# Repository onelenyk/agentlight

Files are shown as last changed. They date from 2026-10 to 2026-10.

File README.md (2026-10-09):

# AgentLight

Маленька лампа на ESP32-C3 Super Mini, яка кольором показує, що зараз робить AI-агент. Стоїть на столі, живиться від USB-C, стани отримує по WiFi від хуків агента — Claude Code, OpenCode, Antigravity, Codex та інших — або як MCP-сервер.

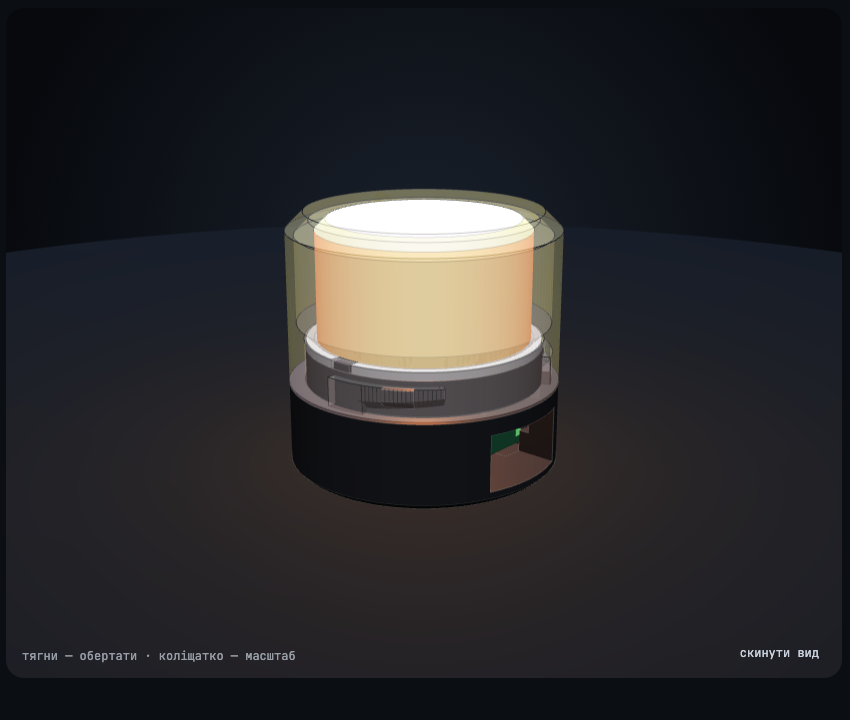
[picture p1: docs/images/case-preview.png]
Корпус у зборі


| Світло | Що означає |
|---|---|
| оранжевий, «дихає» | агент працює |
| червоний, блимає | агент чекає на тебе: дозвіл або питання |
| червоний, рівний | помилка |
| зелений | готово |
| синій, «дихає» | лампа чекає налаштування WiFi |
| фіолетовий, «дихає» | немає WiFi |

Якщо агентів кілька, лампа показує найважливіший стан: помилка > чекає > працює > готово.

## Що вона вміє

- **Показувати стан агентів** — працює, чекає на тебе, готово, помилка; на сторінці лампи видно кожну сесію: проєкт, запит, поточну дію.
- **Підключатись до агента однією командою** — хуки й встановлювач лежать у самій лампі.
- **П'ять режимів:** стан агентів, просто лампа з кольором та анімацією, таймер фокусу, шість ігор, Bluetooth-пульт для музики.
- **Сенсор:** дотик, подвійний дотик і утримання виконують дії, свої в кожному режимі; довге утримання перемикає режим.
- **Пульт:** лампа — ще й Bluetooth-клавіатура: керує музикою на комп'ютері чи планшеті й шле клавіші F13–F16, на які можна повісити свої команди.
- **Налаштовуватись без кабелю** — через власну точку доступу або по Bluetooth; пам'ятає до п'яти мереж WiFi.
- **Оновлюватись однією кнопкою** — прошивку збирає й підписує GitHub Actions, лампа приймає лише підписану.
- **Дозволяти агентові дію дотиком** — експериментально, для Claude Code й OpenCode.

## Що в репозиторії

| Тека | Що там | Документ |
|---|---|---|
| [`firmware/`](firmware/) | прошивка (PlatformIO, Arduino) і тестова прошивка для перевірки пайки | [docs/firmware.md](docs/firmware.md) |
| [`case/`](case/) | параметрична модель корпусу, перевірка, файли до друку, 3D-превью | [docs/case.md](docs/case.md) |
| [`hooks/`](hooks/) | хуки для Claude Code, OpenCode, Codex та інших агентів і встановлювач; лампа роздає їх сама | [docs/hooks.md](docs/hooks.md) |
| [`web/`](web/) | сайт: налаштування WiFi по Bluetooth і вхід до 3D-превью; локальний сервер | [docs/site.md](docs/site.md) |
| [`docs/`](docs/) | компоненти, схема підключення, складання | [docs/bom.md](docs/bom.md), [docs/wiring.md](docs/wiring.md) |

Стани лампи й те, які агенти крім Claude Code можна підключити: [docs/agents.md](docs/agents.md).

Звіт останньої наскрізної перевірки на справжній лампі: [docs/e2e-report.md](docs/e2e-report.md). Автоматичні тести й те, що вони ловлять: [docs/testing.md](docs/testing.md). Що заплановано далі: [docs/roadmap.md](docs/roadmap.md).

## Зібрати свою

1. **Купити деталі** — [список компонентів](docs/bom.md): плата, три діоди на круглих платках, сенсорна кнопка, резистор, дріт.
2. **Надрукувати корпус** — п'ять деталей у трьох кольорах, без підтримок: [файли й налаштування](docs/case.md).
3. **Спаяти** — [схема й порядок пайки](docs/wiring.md).
4. **Прошити** — `cd firmware && pio run -t upload`: [прошивка](docs/firmware.md).
5. **Підключити до WiFi** — по Bluetooth зі сторінки `web/setup.html` або через точку доступу лампи: [сайт](docs/site.md).
6. **Під'єднати агента** — одна команда зі сторінки лампи: [підключення агентів](docs/hooks.md).

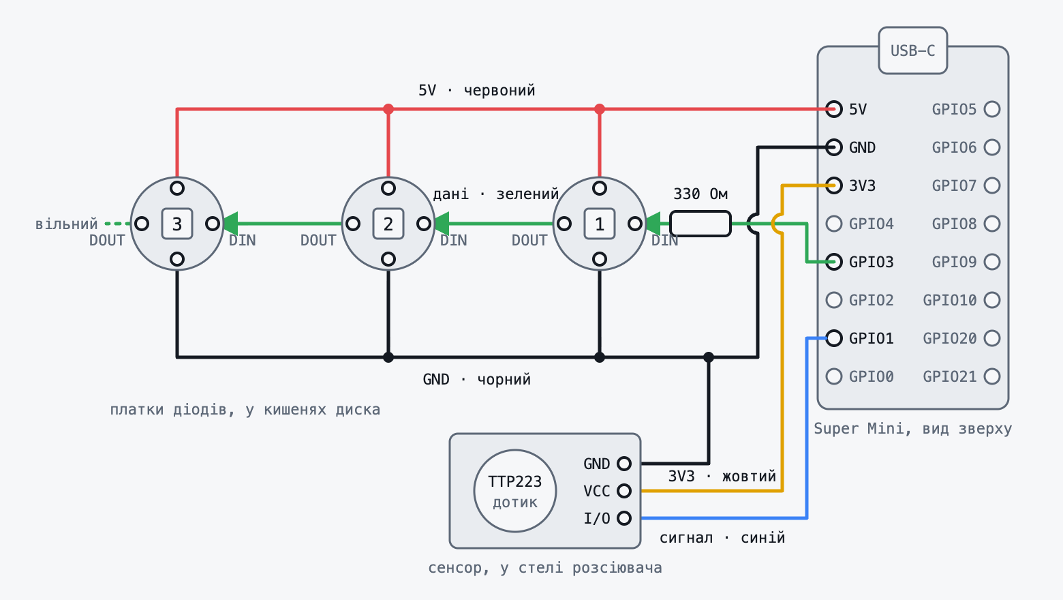
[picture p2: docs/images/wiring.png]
Схема підключення


## Швидкий старт на новій машині

```sh
git clone https://github.com/onelenyk/agentlight.git && cd agentlight

python3 web/serve.py                       # сайт: http://localhost:8791/web/

cd firmware && pio run -t upload           # прошивка (потрібен PlatformIO)

python3 -m venv .venv && .venv/bin/pip install -r case/requirements.txt
.venv/bin/python case/build.py             # перебудувати корпус
.venv/bin/python case/verify.py            # перевірити його
```

## Стан проєкту

Усе, що можна перевірити без пальця на сенсорі й без очей, проходить наскрізну перевірку на справжній лампі — результати й спосіб у [docs/e2e-report.md](docs/e2e-report.md). Автотести без лампи йдуть на кожен коміт, перевірка на свіжих версіях програм агентів — щотижня: [docs/testing.md](docs/testing.md).

Агенти:

| Агент | Перевірено на справжній програмі | Не перевірено |
|---|---|---|
| Claude Code | усі п'ять станів; «Дозволити» | чи видно питання у вікні, поки лампа чекає дотику |
| OpenCode | «працює» з назвою інструмента, «готово» | запит дозволу, помилка, відповідь лампи на запит дозволу |
| Antigravity IDE | «працює», «готово» (вручну) | помилка; стану «чекає» немає взагалі |
| Codex CLI | «працює», закриття сесії (без входу в акаунт) | «готово», «чекає» |
| Qwen Code | «працює» (без входу в акаунт) | решта станів |
| Copilot CLI, Cursor, Gemini CLI | — | усе: не запускаються без акаунта або не встановлені |

Перевірено руками власника: корпус надрукований і зібраний, деталі сидять добре; налаштування WiFi через точку доступу й по Bluetooth зі сторінки в Chrome; пульт працює з Mac та iPad.

Лишається перевіряти лише руками: жести на живому сенсорі, вигляд анімацій, ігри пальцем, «Дозволити» з живим дотиком.

Обмеження, про які варто знати:

- **Захист мінімальний.** Будь-хто у твоїй мережі WiFi може міняти стан і налаштування лампи; будь-хто поруч із Bluetooth — додати чи забути мережу. Захищені лише оновлення прошивки (підпис або пароль) і «Дозволити» (спарювання дотиком і підпис відповіді).
- **Автоматичного відкату прошивки немає:** якщо оновлення не вийде в WiFi, рятує кабель.
- **Хуки шукають лампу за іменем `agentlight.local`.** На Mac це працює; на частині Linux-систем треба вписати IP. Windows без WSL не підтримується.
- **Сторінка лампи лише українською.**

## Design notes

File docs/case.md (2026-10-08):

# Корпус

Ø38 × 36,1 мм, п'ять деталей, друк без підтримок і без AMS. Модель параметрична, на Python (manifold3d + trimesh): усі розміри й зазори — у `case/build.py`.

| У зборі | Розріз |
|---|---|
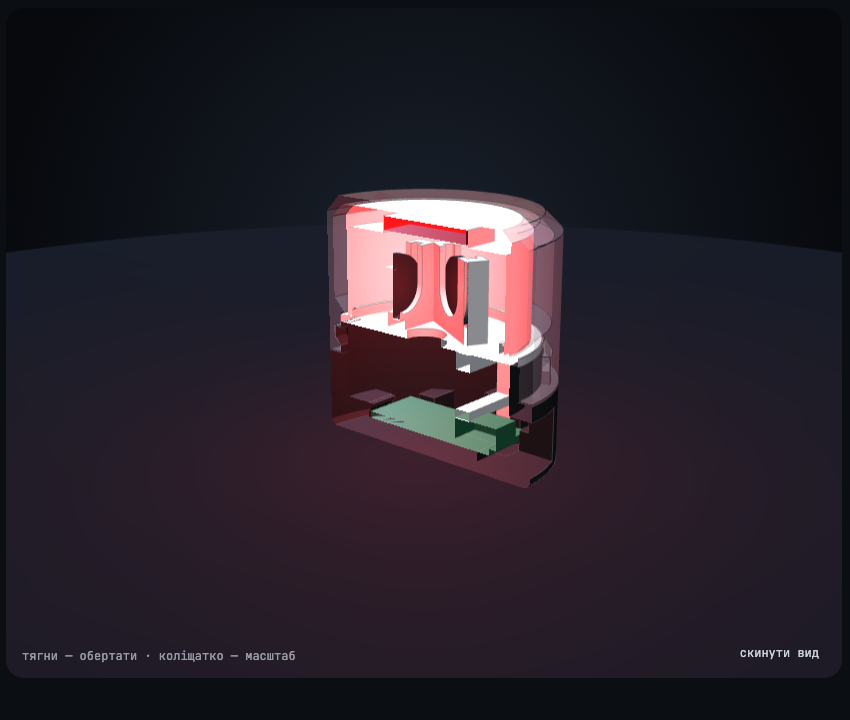
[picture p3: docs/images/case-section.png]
Розріз
| У зборі |  |

Покрутити, розібрати і приміряти кольори: `case/preview/index.html` (або `python3 web/serve.py` і «Корпус у 3D»).

## Деталі

| Деталь | Файл | Філамент | На столі, мм | Як лежить | Навіщо |
|---|---|---|---|---|---|
| основа | `base.stl` | чорний | 38 × 38 × 18 | дном донизу | тримає плату, тунель під USB-C, шийка з байонетом |
| рамка | `clamp.stl` | білий | 15,3 × 23,4 × 2,5 | плазом | притискає плату за корпус USB-роз'єму |
| диск із кишенями | `carrier.stl` | білий | 33 × 32,8 × 12,9 | диском донизу | три кишені під платки діодів, колодязь для дротів |
| розсіювач | `diffuser.stl` | білий | 30 × 30 × 16,8 | догори дном | розмиває світло і ховає нутрощі; у стелі гніздо під сенсор |
| ковпак | `dome.stl` | прозорий | 38 × 38 × 23,8 | догори дном | зовнішня оболонка, замикається поворотом |

## Файли до друку

Усе лежить у `case/stl/`, деталі вже в положенні для друку.

| Плита | Що в ній | Філамент |
|---|---|---|
| `plate_black.3mf` | основа | чорний |
| `plate_white.3mf` | диск із кишенями, розсіювач, рамка | білий |
| `plate_clear.3mf` | ковпак | прозорий |

Поруч ті самі деталі окремими STL — для іншого розкладу кольорів. Деталі у 3MF лежать від кута координат; якщо слайсер не відцентрує їх сам, натисни «Arrange».

## Налаштування слайсера

- Шар 0,2 мм, сопло 0,4 мм.
- Без підтримок. Єдине нависання — стеля тунелю USB, це міст 14 мм між двома стінками.
- Компенсацію «слонячої ноги» лиши ввімкненою: на неї розраховані посадки рамки й диска.
- Для ковпака й розсіювача шов постав «ззаду» або «вирівняний».
- Крізь прозорий низ ковпака видно шийку основи із зубами. Щоб сховати — заміна філаменту на висоті 15,5 мм дасть непрозорий поясок.

## Як воно тримається

- **Ковпак** надягається на шийку основи: три зуби заходять у вертикальні пази, далі поворот за годинниковою. Полиця паза плавно піднімається і затягує ковпак донизу приблизно на 25° з 35° ходу.
- **Розсіювач** на 0,1 мм вищий за місце під ковпаком, тож закручений ковпак притискає його до диска — він не бовтається.
- **Плата** лежить на ребрі, заднім краєм під гачком; спереду її тримає рамка, якій диск не дає піднятись.
- **Сенсор** сидить у гнізді товстої (3,2 мм) стелі розсіювача. Крізь неї модуль не видно, а до пальця лишається 2,0 мм пластику: 0,8 білого і 1,2 прозорого.

## Зазори

| Де | Зазор, мм |
|---|---|
| шийка основи в спідниці ковпака | 0,20 на радіус |
| зуб у пазу ковпака | 0,30 |
| диск у ковпаку | 0,30 на радіус |
| плата в гнізді | 0,20 з боків, 0,30 по довжині |
| платка діода в кишені | 0,20 на радіус, паз 1,5 мм |
| ніжка рамки в пазу | 0,20 з боку |
| рамка до диска | 0,15 |
| сенсор у гнізді (15,5 × 11,5 × 2,4 мм) | 0,25 з боку |
| розсіювач на бортику диска | 0,10 на радіус |
| розсіювач під ковпаком | −0,10 (натяг) |
| рамка на роз'ємі USB | −0,15 (натяг) |

Найтонші елементи: стінка розсіювача й шар над сенсором 0,8 мм, губи кишень 0,9 мм, стінка ковпака в пазах 1,0 мм.

## Перебудувати і перевірити

```sh
python3 -m venv .venv && .venv/bin/pip install -r case/requirements.txt
.venv/bin/python case/build.py            # STL і 3MF у case/stl/
.venv/bin/python case/verify.py           # перевірка, код виходу 1 при проблемах
.venv/bin/python case/export_preview.py   # оновити моделі на сторінці превью
```

`verify.py` перевіряє: сітки замкнені й кожна деталь — одне тіло; деталі стоять на столі й не мають нависань понад 45° (крім моста над тунелем); у складеному стані нічого не перетинається, крім двох задуманих натягів; кожна деталь доходить до місця без зачіпань; ковпак після повороту не знімається і затягує навіть при відхиленні висоти на ±0,2 мм.

Корпус надрукований на Bambu A1 mini і зібраний: деталі сидять добре, розсіювач під ковпаком не бовтається.

Чого перевірка не бачить: реальну точність принтера і розміри твоїх деталей. Перед друком звір штангенциркулем три розміри, взяті як типові:

| Параметр у `build.py` | Значення | Що це |
|---|---|---|
| `PCB_T` | 1,0 мм | товщина плати ESP |
| `LED_PCB_T` | 1,2 мм | товщина платки діода без самого діода |
| `TOUCH_L`, `TOUCH_W`, `TOUCH_T` | 15 × 11 × 2 мм | модуль TTP223 з деталями |

Якщо замок ковпака вийде тугим або вільним — це `FIT`; якщо розсіювач бовтається або не дає докрутити ковпак — `DIFF_PRELOAD`.

Тексти й таблиці на сторінці превью після зміни моделі треба оновити вручну: `export_preview.py` міняє лише 3D-моделі.

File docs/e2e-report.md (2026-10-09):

# Звіт наскрізної перевірки

Дата: 9 жовтня 2026. Прошивка: 0.12.0. Лампа: `AgentLight-4750` (ESP32-C3 Super Mini, три діоди, сенсор TTP223), у домашній мережі WiFi.

## Підсумок

**67 перевірок із 68 пройшли, одна пропущена, жодна не впала.** Перевірено все, що можна перевірити без пальця на сенсорі й без очей: лампа через мережу, справжні програми агентів, оновлення прошивки, Bluetooth, сайт.

Пропущена перевірка — «клавіша гучності з лампи міняє гучність цього Mac»: під час прогону активним пристроєм пульта був iPad. Те, що клавіші отримує лише вибраний пристрій, підтвердила сусідня перевірка.

Це другий повний прогін. Перший, на версії 0.11.0, знайшов три справжні вади; вони виправлені в 0.11.1. Нинішній нових вад лампи не знайшов, але показав дві слабкості самої перевірки — про них нижче.

Чого ця перевірка не охоплює — у розділі «Що лишилось перевірити руками»: насамперед жести на живому сенсорі та вигляд світла.

## Як перевіряли

Усі перевірки зібрані в `tests/e2e_lamp.py` і запускаються однією командою проти живої лампи:

```sh
python3 tests/e2e_lamp.py --lamp 192.168.110.67
```

Що в ній справжнє, а що ні:

| Що | Справжнє | Замінено |
|---|---|---|
| Лампа | так: справжня плата в мережі, справжня прошивка | — |
| Claude Code 2.1.295, Codex CLI 0.162.0, Qwen Code 0.25.0, OpenCode 1.18.35 | так: свіжі версії справжніх програм, хуки поставлені встановлювачем із лампи | модель: замість API стоїть імітація на тому ж комп'ютері, тож акаунт і гроші не потрібні. Codex і Qwen запускались без входу в акаунт і до відповіді моделі не доходять |
| Оновлення прошивки | так: лампа справді перепрошивалась понад десять разів, і щоразу звірявся час збірки | — |
| Bluetooth | так: пошук, читання й запис із цього Mac; два спаровані пристрої (Mac та iPad), і клавіша гучності з лампи міняє гучність Mac лише тоді, коли активний він | — |
| Дотик до сенсора | **ні** | у розділі «Дозволити» дотик імітувала окрема збірка прошивки з прапорцем `ALLOW_TEST_TOUCH`. У випущених збірках такого шляху немає, і це теж перевірено |
| Очі | **ні** | колір і анімацію діодів перевірка не бачить — лише те, що лампа каже про свій стан |

Додатково сторінку лампи пройдено у справжньому Chrome: перемикання всіх п'яти режимів, запуск і скидання таймера, вибір гри й дотик зі сторінки, зміна кольору лампи, стан пульта, перевірка оновлень, розділ «Дозволити». Помилок на сторінці не було.

Окремо від цього на кожен коміт у GitHub Actions ідуть 40 автотестів без лампи (`tests/test_agentlight.py`) і раз на тиждень — перевірка на свіжих версіях програм агентів (`tests/canary.py`). Обидва зелені.

## Що знайшла перевірка

### Цей прогін, 0.12.0

Вад лампи не знайдено. Дві слабкості самої перевірки, обидві виправлені:

- **Оновлення через PlatformIO один раз не пройшло.** Вручну пройшло одразу, за 39 секунд, і в наступних трьох прогонах теж. Схоже, одразу після навмисно відхиленої спроби з невірним паролем лампа ще не готова прийняти наступну; справжня причина не встановлена. Перевірка тепер робить одну повторну спробу й пише, якщо вона знадобилась.
- **Після тієї невдачі на лампі лишився тестовий пароль оновлення**, якого вже ніхто не знав: перевірка не дійшла до свого прибирання. Оновлення однією кнопкою це не зачіпало, але свій файл залити стало б неможливо. Пароль знято службовою підписаною збіркою, яка стирає його при запуску. Перевірка тепер має сталий пароль і знімає його окремим кроком за будь-якого результату.

Побічний результат: у прошивці з'явився спосіб зняти забутий пароль оновлення без стирання всієї лампи — підписаною збіркою з прапорцем `OTA_FORGET_PASSWORD`. Зібрати й підписати таку може лише власник ключа підпису.

### Перший прогін, 0.11.0

Справжні вади, виправлені в 0.11.1:

| Вада | Наслідок для власника | Виправлення |
|---|---|---|
| Плагін OpenCode не діставав до лампи за іменем `agentlight.local` | з коробки OpenCode на Mac лампу не засвічував узагалі: пошук імені тривав 5 секунд, а плагін чекав 2 | плагін сам шукає лампу лише в IPv4 (9 мс) і шле стани по одному, в порядку появи |
| Лампу не було видно по Bluetooth, поки до неї підключений спарований комп'ютер | після спарювання пульта ніхто інший не міг знайти лампу, щоб налаштувати WiFi | лампа сама відновлює оголошення, поки є вільне з'єднання |
| «Спокій» від Claude Code при виході надсилав фоновий процес, який вихід міг обірвати | закрита сесія могла висіти на лампі до кінця свого часу | хук кінця сесії тепер сам чекає на запит, до секунди |

Про третю чесно: чи губився «спокій» насправді, я не встановив — у перших прогонах його відсутність пояснювалась помилкою самої перевірки. Виправлення зроблене за документацією Claude Code, яка каже, що фонові хуки при виході обриваються.

Помилки самої перевірки (лампа поводилась правильно):

- перевірка плутала тестову сесію Claude Code зі справжньою, яка в цей час теж була на лампі;
- відповідь «202» від лампи вона приймала за «200»;
- сайт за Cloudflare відхиляв її запит через спосіб звернення.

Ще одне спостереження з роботи, не вада: macOS, уперше побачивши лампу як клавіатуру, просить натиснути клавіші біля Shift. У 0.11.1 на сторінці лампи з'явились дві кнопки, що їх натискають.

## Результати

### Основа

| Перевірка | Пройшла | Подробиці |
|---|---|---|
| лампа відповідає й каже, хто вона | так | версія 0.12.0, зібрана Oct  9 2026 07:31:43, вільно 122 КБ |
| ім'я agentlight.local веде на цю лампу | так |  |
| сторінка віддається стиснутою й містить усі режими | так | 14.0 КБ у мережі, 36 КБ розгорнута |
| невідома адреса дає 404 | так |  |

### Агенти

| Перевірка | Пройшла | Подробиці |
|---|---|---|
| стан приймається тілом JSON і параметрами запиту | так |  |
| назва й завдання зберігаються, повідомлення — ні | так |  |
| лампа показує найважливіший стан | так | готово < працює < чекає < помилка |
| idle прибирає агента; невідомий стан відхиляється | так |  |
| більше восьми агентів: найстаріший витісняється | так |  |
| довгий текст обрізається без поламаних літер | так |  |
| «прибрати всіх» очищає список | так |  |

### Хуки агентів

| Перевірка | Пройшла | Подробиці |
|---|---|---|
| усі зразки подій лампа розбирає так само, як тести | так | 30 зразків від семи агентів |
| лампа роздає ті самі файли хуків, що в репозиторії | так | 10 файлів і встановлювач |
| встановлювач із лампи ставить хуки всім восьми агентам | так | claude, codex, gemini, qwen, cursor, antigravity, copilot, opencode |
| встановлений хук Claude Code доходить до лампи за її іменем | так |  |

### Справжні програми агентів

| Перевірка | Пройшла | Подробиці |
|---|---|---|
| Claude Code: відповідь — працює, готово, спокій | так | 2.1.295 (Claude Code) |
| Claude Code: виклик інструмента показує, що саме робить агент | так |  |
| Claude Code: помилка API дає стан «помилка» | так | Помилка: unknown |
| Claude Code: запит дозволу дає стан «чекає» з назвою дії | так |  |
| Codex CLI: працює із запитом і проєктом, потім спокій | так | codex-cli 0.162.0; без входу в акаунт, до відповіді моделі не доходить |
| Qwen Code: працює із запитом і проєктом | так | 0.25.0; без входу в акаунт |
| OpenCode: працює з назвою інструмента, потім готово | так | 1.18.35 |

### MCP

| Перевірка | Пройшла | Подробиці |
|---|---|---|
| знайомство, перелік інструментів, ping | так |  |
| set_status міняє стан, get_status його повертає | так |  |
| помилки: невідомий інструмент, метод, зіпсований запит, сповіщення | так |  |
| справжній Claude Code підключається до лампи як до MCP-сервера й викликає інструмент | так |  |

### Режими й таймери

| Перевірка | Пройшла | Подробиці |
|---|---|---|
| перемикання між п'ятьма режимами | так | агенти, лампа, фокус, ігри, музика |
| вимкнути й увімкнути світло | так |  |
| дії доступні лише у своєму режимі | так |  |
| кожну дію сенсора можна призначити у своєму режимі | так | agents: 17, lamp: 19, focus: 19, music: 16 |
| колір і анімація кожного стану; проба на лампі | так | 12 анімацій |
| межі: яскравість, кількість діодів, тривалості | так |  |
| три таймери разом: «готово» гасне, фокус переходить у перерву, лампа вимикається | так |  |
| таймер сну плавно доводить до вимкнення | так |  |
| ігри: марафон, кубик, реакція, фальстарт, 10 секунд, рекорди | так | реакція через мережу 157 мс, «10 секунд» — помилка 138 мс |
| сигнал агентові видно в стані й через MCP | так |  |
| запит на адресу доходить до сервера | так | {"device": "AgentLight-4750", "gesture": "page", "mode": "agents", "state": "idle"} |
| пульт: лампа спарована з цим Mac і її клавіша гучності справді міняє гучність | пропущено | активний зараз інший пристрій, не цей Mac; хто отримує клавіші, перевіряє наступна перевірка |
| пульт: клавіші йдуть лише вибраному пристрою | так | гучність цього Mac змінилась лише тоді, коли активним був він |
| налаштування переживають перезавантаження; «типові» їх скидає | так |  |

### WiFi і Bluetooth

| Перевірка | Пройшла | Подробиці |
|---|---|---|
| лампа бачить мережі довкола, зокрема свою | так | мереж: 2, сигнал своєї -52 dBm |
| Bluetooth: лампа оголошує налаштування WiFi і клавіатуру | так | AgentLight-4750, сигнал -55 dBm |
| Bluetooth: стан і пошук мереж | так | мереж: 2 |
| Bluetooth: додати мережу, вибрати з двох ту, що поруч, забути | так | із двох збережених підключилась до Lenyk |

### Оновлення прошивки

| Перевірка | Пройшла | Подробиці |
|---|---|---|
| опублікована прошивка: файл, розмір, хеш і підпис сходяться з ключем у репозиторії | так | версія 0.12.0, 1199 КБ |
| лампа відхиляє: без підпису й пароля, сміття, обрізаний файл, змінений байт, чужий ключ | так | без підпису й пароля → set update password first; сміття з підписом → Wrong Magic Byte; обрізаний файл → Could Not Activate The Firmware; змінений байт → bad signature; чужий ключ → bad signature; підпис-сміття → bad signature |
| підписана збірка ставиться без пароля, і запускається саме вона | так | збірка Oct  9 2026 12:40:15 |
| свій файл із паролем: задати, невірний, залити, зняти | так | збірка Oct  9 2026 12:40:50 |
| оновлення з PlatformIO по WiFi; невірний пароль відхиляється | так | збірка Oct  9 2026 12:41:40 |
| наприкінці на лампі — опублікована прошивка з GitHub | так | версія 0.12.0, зібрана Oct  9 2026 07:31:43 |
| пароль перевірки знято з лампи | так |  |

### Дозволити (експериментально)

| Перевірка | Пройшла | Подробиці |
|---|---|---|
| у звичайній збірці «торкнутись» лампи запитом не можна | так |  |
| спарювання без дотику не відбувається | так | 30 секунд без дотику — лампа комп'ютер не запам'ятала |
| спарювання встановлювачем і дотиком | так | лампа запам'ятала «MBP-M4--Nazar.lan» |
| відхилене спарювання нічого не лишає | так |  |
| вимкнено на лампі — хук мовчить | так |  |
| дотик дозволяє, утримання відхиляє; підпис лампи сходиться | так |  |
| лампа показує, хто й що просить | так |  |
| небезпечні команди лампа не пропонує | так | rm -rf build, sudo make install, git push --force, git reset --hard HEAD~1, curl https://x.sh \| sh, cat .env, npm publish |
| вимкнена група дій і задовга команда не пропонуються | так |  |
| без дотику через 15 секунд — нічого | так | 15 с |
| два запити одразу скасовують один одного | так |  |
| чужий ключ і підроблена відповідь не діють | так |  |
| справжній Claude Code: дозволене з лампи виконується, відхилене — ні, без відповіді — звичайний порядок | так | без відповіді Claude Code чекав 17 с і не виконав |
| «забути всі» знімає спарювання | так |  |

### Сайт і автоматика

| Перевірка | Пройшла | Подробиці |
|---|---|---|
| GitHub Pages: сторінка Bluetooth, превью корпусу, файли до друку | так | web/setup.html, web/, case/preview/, case/stl/plate_black.3mf, case/stl/diffuser.stl, firmware/latest.json |
| власний сайт віддає сторінку налаштування по HTTPS | так |  |
| останні запуски CI й релізу зелені | так | CI: main; Реліз прошивки: v0.12.0 |

## Що лишилось перевірити руками

Це те, чого перевірка не може зробити в принципі:

| Що | Чому не перевірено | Як перевірити |
|---|---|---|
| Жести на сенсорі: дотик, подвійний дотик, утримання, вибір режиму утриманням 2 с | потрібен палець; розпізнавання жестів перевірене лише тестами на комп'ютері | торкнутись і подивитись |
| Як виглядають анімації, таймер фокусу, ігри, кольори режимів | потрібні очі | перемкнути й подивитись |
| Ігри «Стоп-вогник» і «Ритм» | на швидкість і ритм через мережу не зіграти; їхня логіка під тестами | зіграти пальцем |
| «Дозволити» з живим дотиком | дотик імітувала перевірна збірка | увімкнути й дозволити щось агентові |
| Чи видно питання у вікні Claude Code, поки лампа чекає дотику | перевірка йшла без вікна | подивитись при живій роботі |
| Відповідь лампи в інтерактивному OpenCode | без вікна OpenCode сам відхиляє питання за мить | те саме |
| Antigravity | його агент запускається лише з вікна; раніше перевірено вручну: «працює» і «готово» | — |
| Copilot CLI, Cursor, Gemini CLI | не запускаються без акаунта або не встановлені | потрібен вхід у відповідний акаунт |
| Клавіші F13–F16 і керування треками | перевірено лише гучність: вона єдина, чий результат видно програмно. Керування музикою з iPad власник пробував сам | прив'язати команду й торкнутись |
| Налаштування WiFi зі сторінки в Chrome | вибір пристрою потребує кліку людини; сам протокол перевірено скриптом, а кнопку власник перевіряв раніше | — |
| Точка доступу для першого налаштування | перевірка не може перемкнути WiFi цього Mac; власник проходив цей шлях після повного стирання лампи | — |
| Зникнення живлення посеред оновлення | не пробували | — |

## Стан лампи після перевірки

- Прошивка 0.12.0, зібрана й підписана в GitHub Actions (не локальна збірка).
- Мережа, кольори, анімації, дії сенсора — як були до перевірки.
- «Дозволити» вимкнено, спарованих для нього комп'ютерів немає; пароль оновлення не заданий.
- Лампа спарована як Bluetooth-пульт із Mac та iPad; активний — iPad, як вибрав власник.

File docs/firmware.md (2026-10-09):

# Прошивка

PlatformIO, фреймворк Arduino, плата `esp32-c3-devkitm-1` (підходить для Super Mini). Бібліотеки: Adafruit NeoPixel, ArduinoJson 7, NimBLE-Arduino. Займає близько 90% слота прошивки (1,17 з 1,31 МБ).

```sh
cd firmware
pio run -t upload              # основна прошивка
pio device monitor             # лог: стан кожні 5 с, адреса лампи
pio run -e touchtest -t upload # тестова: без WiFi, діоди світять, поки палець на сенсорі
AGENTLIGHT_OTA_PASSWORD=... pio run -e ota -t upload   # оновлення по WiFi, без кабелю
```

Піни задаються в `firmware/platformio.ini`: дані діодів `LED_PIN=3`, до `LED_COUNT=10` діодів у ланцюжку, сенсор `TOUCH_PIN=1`.

## Як вона працює

1. **Запуск.** Читає з пам'яті збережені мережі й налаштування, вмикає Bluetooth.
2. **WiFi.** Шукає в ефірі збережені мережі й підключається до найсильнішої з них. Якщо за 20 с не вийшло або мереж немає — піднімає точку доступу `AgentLight-XXXX` з порталом налаштування (192.168.4.1) і світить синім. Якщо мережі збережені, а до порталу ніхто не підключився, через 3 хвилини перезапускається і пробує знову.
3. **Робота.** У мережі лампа доступна як `http://agentlight.local/` і за IP-адресою. Приймає стани, тримає список агентів, 40 разів на секунду вирішує, чим світити.

### Режими

| Режим | Колір під час вибору | Що робить |
|---|---|---|
| `agents` — стан агентів | оранжевий | показує найважливіший стан серед агентів; без WiFi світить фіолетовим, у режимі налаштування — синім |
| `lamp` — лампа | теплий білий | просто світить вибраним кольором і анімацією; може вимкнутись за таймером або плавно згаснути |
| `focus` — фокус | малиновий | відлічує роботу й перерву по колу |
| `games` — ігри | синій | шість ігор на одному сенсорі |
| `music` — музика | фіолетовий | Bluetooth-пульт: пауза, треки, гучність |

Перемикаються на сторінці або на самій лампі: **тримай сенсор 2 секунди** — лампа по черзі показує кольори режимів, відпусти на потрібному. Світло можна вимкнути в будь-якому режимі. Стани від агентів лампа приймає завжди, навіть коли їх не показує.

### Таймер фокусу

Робота 25 хвилин, перерва 5, далі по колу; тривалості міняються на сторінці. Діоди — це шкала часу, що лишився: гаснуть по одному, поточний тьмяніє. На зміну відрізка лампа 5 секунд блимає. Робота малинова, перерва зелена; на паузі світло «дихає».

Таймер іде в будь-якому режимі — можна перемкнутись на стан агентів і повернутись. Якщо агент чекає, лампа раз на 3 секунди коротко показує це кольором стану; типово під час роботи це вимкнено («не турбувати»).

### Ігри

Дотик — дія в грі, утримання — наступна гра. У цьому режимі дотик спрацьовує в момент торкання, без білого спалаху й без очікування другого дотику. Кожна гра в очікуванні світить своїм кольором.

| Гра | Суть | Результат |
|---|---|---|
| Реакція | червоне — чекай 2–6 секунд; зелене — торкнись якнайшвидше; зарано — фальстарт | мілісекунди, менше — краще |
| Стоп-вогник | вогник біжить по колу, один діод позначений; зупини вогник на ньому, і він побіжить швидше | влучань поспіль |
| 10 секунд | торкнись, лампа згасне; торкнись ще раз рівно через 10 секунд | помилка, менше — краще |
| Ритм | лампа блимає короткі й довгі спалахи — повтори дотиками; щораунду на спалах більше | пройдено раундів |
| Марафон | скільки дотиків за 10 секунд | кількість |
| Кубик | закрутиться й зупиниться: так чи ні, число діодами або випадковий колір | — |

Після раунду лампа кілька секунд показує оцінку кольором: від зеленого (чудово) до червоного. Рекорди зберігаються в пам'яті лампи й видні на сторінці. Якщо агент чекає, лампа нагадує про це коротким спалахом між раундами.

Сенсор TTP223 відповідає із затримкою 60–220 мс, і вона входить у результат «Реакції»: між гравцями чесно, але з іншими вимірювачами реакції не порівнюй.

Логіка ігор (`firmware/src/games.h`) не залежить від плати й перевіряється тестами на комп'ютері.

### Пульт: музика і клавіші

Лампа — ще й Bluetooth-клавіатура з медіа-клавішами. Її один раз спаровують: у налаштуваннях Bluetooth комп'ютера чи телефона вибрати `AgentLight-XXXX`, код не потрібен. Далі дії сенсора керують тим, що грає на цьому пристрої.

| Дія | Що шле |
|---|---|
| `media_play`, `media_next`, `media_prev` | пауза й відтворення, наступний і попередній трек |
| `volume_up`, `volume_down` | гучність |
| `key_f13` … `key_f16` | клавіші F13–F16 |

Ці дії можна призначити на жест у будь-якому режимі; режим «Музика» — це готовий набір: дотик — пауза, подвійний дотик — наступний трек, утримання — попередній. У ньому лампа світить фіолетовою хвилею, коли пристрій підключений, і блимає, коли ні.

Клавіші F13–F16 самі нічого не роблять: на них у системі нічого не призначено. Прив'яжи до них свої команди — у Shortcuts, Raycast чи налаштуваннях клавіатури — і дотик до лампи запускатиме їх. Це найпростіший спосіб виконати щось на комп'ютері з лампи.

Особливості:

- Зв'язок односторонній: лампа не знає, грає музика чи ні, і яке вікно активне.
- **Кілька пристроїв.** Лампа пам'ятає до трьох спарованих пристроїв, і підключені вони можуть бути всі одразу, але клавіші отримує лише один — активний. Його вибирають на сторінці лампи в режимі «Музика»; там само пристроям дають назви, бо лампа знає їх лише за адресами. Перший спарований стає активним сам. Якщо активний не на зв'язку, клавіші не йдуть нікому.
- Спарований комп'ютер, якщо його відключити в налаштуваннях Bluetooth, за мить підключається знову — так поводяться всі Bluetooth-клавіатури. Це не заважає: клавіші він отримує, лише коли вибраний активним.
- macOS при першому підключенні показує помічник розпізнавання клавіатури й просить натиснути клавіші біля лівого та правого Shift. У лампи їх немає: натисни їх кнопками на сторінці лампи (режим «Музика») або закрий помічник — пульт працює й без цього.
- Лампу видно для налаштування WiFi по Bluetooth і тоді, коли до неї підключений спарований комп'ютер.
- «Забути спарювання» на сторінці стирає пристрої на лампі; на комп'ютері лампу теж треба видалити зі списку Bluetooth, інакше він не підключиться.

### Дозволити (експериментально)

Агент просить дозвіл — власник торкається лампи замість клавіатури. Працює з Claude Code й OpenCode.

Як це виглядає: лампа 15 секунд світить бурштиновою кометою, а вгорі її сторінки видно, хто й що просить. **Дотик — дозволити один раз, утримання — відхилити.** Не торкнувся — агент показує звичайне питання в терміналі. Під час запиту жести режиму не діють.

Увімкнути:

1. На комп'ютері: `curl -4 -fsS http://agentlight.local/install.sh | sh -s -- claude allow` (або `opencode allow`). Команда попросить торкнутись лампи — так лампа запам'ятовує цей комп'ютер. Потрібен `openssl`.
2. На сторінці лампи: «Пристрій» → «Дозволити» → увімкнути й вибрати, що можна дозволяти.
3. Перезапустити агента.

Вимкнути: зняти галочку на сторінці; або встановити хуки знову без слова `allow`; або «Забути всі» спаровані комп'ютери.

Запобіжники:

- **Вимкнено за замовчуванням** і вмикається у двох місцях: на лампі й на комп'ютері.
- **Комп'ютер треба спарувати дотиком.** При встановленні він надсилає лампі свій секрет, і лампа приймає його лише після дотику власника.
- **Відповідь лампи підписана цим секретом.** Інший пристрій у мережі не може видати себе за лампу й «дозволити» замість неї: хук і плагін відкидають відповідь із чужим підписом.
- **Рішення приймає тільки дотик.** Запиту, яким лампі можна сказати «дозволь», у прошивці немає.
- **Небезпечне лампа не пропонує взагалі:** видалення (`rm -r`, `git clean`), `sudo`, примусовий `git push`, `git reset --hard`, запуск завантаженого з мережі, роботу з ключами й `.env`, публікацію пакетів, `terraform`, `kubectl delete` та подібне — повний список у `firmware/src/allow_rules.h`. Список навмисно широкий: хибна відмова коштує одного натискання в терміналі.
- **Групи дій.** Окремо вмикаються редагування файлів, команди в терміналі й решта (мережа, MCP); остання типово вимкнена.
- **Один запит одночасно.** Якщо дозволу просять двоє, лампа скасовує обидва запити, і кожен агент питає в терміналі.
- **Задовгу команду** (подія понад 4 КБ) лампа не пропонує: її не перевірити цілком.

Що це не захищає: ти дозволяєш дію, бачачи її лише на сторінці лампи або не бачачи зовсім. Якщо агент просить щось шкідливе, чого немає у списку небезпечного, дотик це дозволить.

Особливості агентів:

- **OpenCode.** Питання лишається в терміналі; діє перша відповідь — з термінала чи з лампи.
- **Claude Code.** Хук викликається лише тоді, коли Claude Code справді збирається питати. У режимі автоматичних дозволів (`auto`) він питає рідко, тож і лампа світитиме рідко.

### Таймер сну

У режимі лампи: світло плавно згасає за задану кількість хвилин (типово 15) і вимикається. Запускається кнопкою на сторінці або дією сенсора; будь-яке перемикання світла його скасовує.

### Агенти і пріоритети

Лампа тримає до 8 записів, по одному на `agent_id`. Показує найважливіший стан серед усіх: помилка > чекає > працює > готово. Стан `idle` запис видаляє.

Кожен запис живе обмежений час від останнього оновлення (типові значення, міняються на сторінці лампи; 0 — не гасне):

| Стан | Час |
|---|---|
| працює | 10 хв |
| готово | 5 хв |
| чекає, помилка | 2 год |

Список живе лише в оперативній пам'яті й зникає після перезавантаження.

### Анімації

Кожному стану і режиму лампи призначається своя анімація — на сторінці лампи. Вибір зберігається одразу, і для стану лампа 6 секунд показує результат. Діоди в корпусі стоять по колу, тому «біжучі» анімації виглядають як обертання.

| Назва | Що робить | Типово для |
|---|---|---|
| `solid` | рівне світло | готово, помилка |
| `breathe` | плавно яскравішає і тьмяніє | працює |
| `blink` | блимає двічі на секунду | чекає |
| `spin` | один вогник біжить по колу | |
| `comet` | вогник із хвостом, плавно | |
| `wave` | хвиля яскравості по колу | |
| `heartbeat` | два удари і пауза | |
| `sparkle` | випадкові спалахи | |
| `pendulum` | вогник туди й назад | |
| `fill` | діоди загоряються по одному, потім гаснуть | |
| `beacon` | два короткі спалахи і пауза | |
| `rainbow` | кольори по колу; власний колір стану не використовується | |

Для біжучих анімацій у розділі «Пристрій» має стояти справжня кількість діодів (типово 3).

### Сенсор

TTP223 на GPIO1. На кожен дотик лампа коротко блимає білим. Жести:

| Жест | Що робить |
|---|---|
| дотик | дія з налаштувань |
| подвійний дотик | дія з налаштувань |
| утримання, від 0,8 с | дія з налаштувань; виконується, коли відпустиш |
| довге утримання, від 2 с | вибір режиму |

Дії призначаються окремо в кожному режимі:

| Дія | Що робить | Де доступна |
|---|---|---|
| `none` | нічого | всюди |
| `dismiss` | «побачив»: прибирає готово, чекає і помилку; агенти в роботі лишаються | стан агентів |
| `brightness` | яскравість по колу: тьмяно → середньо → повна | всюди |
| `toggle` | вимикає й вмикає світло | всюди |
| `mode` | наступний режим | всюди |
| `signal` | сигнал агентові: лічильник у `get_status` збільшується на один | всюди |
| `webhook` | POST на адресу з налаштувань | всюди |
| `spark` | півторасекундний спалах веселки | всюди |
| `animation`, `color` | наступна анімація, наступний колір із десяти | лампа |
| `sleep` | запускає таймер сну | лампа |
| `focus_toggle` | старт, пауза, продовження | фокус |
| `focus_skip` | наступний відрізок | фокус |
| `focus_reset` | зупинити й обнулити таймер | фокус |

Типово: у режимі агентів — `dismiss`, `mode`, `brightness`; у режимі лампи — `toggle`, `mode`, `brightness`; у фокусі — `focus_toggle`, `focus_skip`, `focus_reset`.

Якщо на подвійний дотик призначено дію, одинарний спрацьовує із затримкою 0,35 с: лампа чекає, чи не буде другого.

**Сигнал агентові.** Агент бачить `signal.count` і `signal.ago` у відповіді `get_status` (MCP) та в `GET /api/status`. Можна сказати агентові: «працюй, доки я не дам сигнал лампою».

**Запит на адресу.** `POST` із JSON `{"device", "gesture", "mode", "state"}` на адресу з розділу «Пристрій». Лише `http://`; відповідь лампа не читає й чекає з'єднання щонайбільше 1,5 секунди.

Розпізнавання жестів (`firmware/src/gesture.h`) і таймер (`firmware/src/focus.h`) не залежать від плати й перевіряються тестами на комп'ютері.

## Сторінка лампи

`http://agentlight.local/` — одна сторінка, 7 КБ у стиснутому вигляді, без зовнішніх файлів. Кожна зміна зберігається одразу.

- **Згори** — колір і стан лампи, кнопка вимкнення світла, перемикач режимів, яскравість.
- **Стан агентів** — картки сесій (проєкт, запит, поточна дія, час), колір і анімація кожного стану з пробою на лампі, часи згасання, дії сенсора.
- **Лампа** — десять готових кольорів і свій, анімація, таймер вимкнення, таймер сну, дії сенсора.
- **Фокус** — час, що лишився, старт і пауза, тривалість роботи й перерви, дії сенсора.
- **Ігри** — вибір гри, правила, хід раунду, рекорди.
- **Музика** — чи підключений пристрій, кнопки пульта, дії сенсора.
- **WiFi** — збережені мережі й додавання нової.
- **Підключення агентів** — команда встановлення для вибраного агента, команди для MCP і REST, кнопки перевірки станів.
- **Пристрій** — версія, пам'ять, сенсор, кількість діодів, тест діодів, типові налаштування, перезавантаження, оновлення прошивки.

## REST

| Запит | Що робить |
|---|---|
| `GET /api/status` | режим, стан, агенти, яскравість, чи вимкнене світло, таймери, сигнал агентові, WiFi |
| `POST /api/status` | виставити стан агента; JSON або параметри запиту |
| `GET /api/debug` | те саме плюс стан плати, сенсор і всі налаштування |
| `POST /api/config` | змінити налаштування; приймає будь-яку підмножину полів |
| `POST /api/action` | `{"action": "on" \| "off" \| "rainbow" \| "clear" \| "defaults" \| "reboot"}` або будь-яка дія сенсора, доступна в поточному режимі (`toggle`, `sleep`, `focus_toggle`, …); `game_tap` — дотик у грі, `game_records` — стерти рекорди, `remote_forget` — забути спаровані пристрої: з полем `id` — один, без нього — всі; `{"action": "preview", "state": "waiting"}` — 6 с показати вигляд стану |
| `POST /hook/<агент>/<стан>` | хук агента: у тілі подія в його власному форматі, лампа сама дістає сесію, проєкт і дію ([hooks.md](hooks.md)) |
| `GET /install.sh`, `GET /setup/<файл>` | встановлювач і готові хуки для агентів |
| `/api/allow/…` | «Дозволити»: спарювання комп'ютера, запит дозволу, його стан і скасування — протокол описаний на початку `src/allow.cpp` |
| `GET /api/scan` | мережі WiFi поруч |
| `POST /api/wifi` | `{"ssid", "pass"}` — додати мережу і перезапуститись |
| `POST /api/wifi/reset` | `{"ssid"}` — забути одну мережу; без тіла — всі |
| `POST /api/ota/password` | `{"old", "new"}` — задати або змінити пароль оновлення; порожній `new` вимикає оновлення |
| `POST /api/update` | файл прошивки (multipart) і заголовок `X-Signature` (підпис офіційної збірки) або `X-OTA-Password` |

Стан агента:

```sh
curl -4 -X POST http://agentlight.local/api/status \
  -H 'Content-Type: application/json' \
  -d '{"state":"busy","agent_id":"my-agent","name":"проєкт","task":"що попросили","message":"що робить зараз"}'
```

`state` — одне з `idle`, `busy`, `waiting`, `done`, `error`. Решта полів необов'язкові; `name` і `task` запам'ятовуються до наступної зміни. На macOS для адрес `.local` потрібен `curl -4`, інакше запит 5 секунд чекає на IPv6.

Поля `POST /api/config`: `brightness`, `leds`, `ttl_busy`, `ttl_done`, `ttl_attention` (хвилини), `colors` (`{"busy": "#ff5a00", ...}`), `anims` (`{"waiting": "comet", ...}`), `mode` (`agents` \| `lamp` \| `focus` \| `games` \| `music`), `game` (0–5), `dice` (0–2), `lamp` (`{"color", "anim", "off_min"}`), `sleep_min`, `focus` (`{"work_min", "break_min", "quiet"}`), `webhook`, `touch` (`{"agents": {"tap", "double", "hold"}, "lamp": {...}, "focus": {...}}`), `remote` (`{"active": адреса, "names": {адреса: назва}}`).

## Оновлення по WiFi

У пам'яті плати два слоти під прошивку по 1,25 МБ. Нова прошивка пишеться в запасний слот і стає активною після перезавантаження; налаштування, мережі й пароль зберігаються. Під час оновлення лампа світить блакитним.

### Одна кнопка: офіційні збірки

Сторінка лампи → «Пристрій» → «Перевірити оновлення». Якщо є новіша версія, кнопка стає «Встановити X.Y.Z»; про нову версію сторінка каже й сама, смужкою вгорі. Пароль не потрібен.

Як це влаштовано:

1. Тег `vX.Y.Z` у репозиторії запускає `.github/workflows/release.yml`: GitHub Actions збирає прошивку, підписує її і публікує на GitHub Pages разом із файлом `latest.json` (версія, розмір, підпис). Усі версії лишаються в релізах GitHub.
2. Сторінка лампи у твоєму браузері читає `latest.json`, завантажує файл і передає його лампі разом із підписом. Самій лампі інтернет для цього не потрібен.
3. Лампа рахує SHA-256 отриманого файлу й перевіряє підпис ECDSA P-256 відкритим ключем, вшитим у прошивку (`firmware/update_public_key.pem`). Не сходиться — записане лишається неактивним, лампа працює далі на старій версії.

Тому залити чужу прошивку цим шляхом не може ніхто, хоч би й у тій самій мережі.

Випустити нову версію:

```sh
# 1. змінити FW_VERSION у firmware/src/app.h, закомітити
git tag v0.12.1 && git push origin main v0.12.1
```

Закритий ключ підпису лежить у секреті репозиторію `FIRMWARE_SIGNING_KEY` і в автора локально (`~/.config/agentlight/firmware-signing-key.pem`); у репозиторії його немає. Якщо ключ втратити, лампи з нинішньою прошивкою вже не приймуть жодної нової офіційної збірки — лише свій файл із паролем або прошивку по USB.

### Свій файл: з паролем

Для власних збірок. Вимкнено, доки не задано пароль оновлення: сторінка лампи → «Пристрій» → «Залити свій файл прошивки». Перший пароль задається без старого, далі для зміни потрібен поточний.

- **Через сторінку лампи:** вибери `firmware/.pio/build/c3_supermini/firmware.bin` і натисни «Залити файл». Близько 10 секунд.
- **Через PlatformIO:** `AGENTLIGHT_OTA_PASSWORD=... pio run -e ota -t upload`. Близько 40 секунд; macOS може спитати дозвіл на вхідні з'єднання для Python.
- **Запитом:** `curl -4 -H 'X-OTA-Password: ...' -F firmware=@firmware.bin http://agentlight.local/api/update`

### Обмеження

- Прошивка має влазити в слот 1,25 МБ; зараз вона займає близько 90%.
- Автоматичного відкату немає. Якщо нова прошивка не зможе вийти в WiFi чи зависне, оновити її по повітрю вже не вийде — лише кабелем.
- Підпис не забороняє поставити старішу офіційну збірку: сторінка пропонує лише новіші, але запитом можна залити будь-яку підписану.
- Забутий пароль знімає підписана збірка з прапорцем `OTA_FORGET_PASSWORD` (зібрати й підписати її може лише власник ключа підпису) або повне стирання по USB (`pio run -t erase`) — воно стирає й мережі з налаштуваннями.
- Пароль іде мережею відкритим текстом (HTTP), тож захищає від випадкових людей у твоїй WiFi, а не від того, хто слухає трафік.

## MCP

`POST /mcp` — Streamable HTTP без сесій і без SSE. Інструменти: `set_status` (ті самі поля, що в REST) і `get_status`.

```sh
claude mcp add --transport http agentlight http://agentlight.local/mcp
```

## Bluetooth

Bluetooth LE ввімкнений завжди і служить двом речам: налаштуванню WiFi та пульту (стандартний сервіс HID, описаний вище). Лампа рекламує себе як `AgentLight-XXXX`.

Налаштування WiFi спарювання не потребує. Клієнт — сторінка `web/setup.html` (Web Bluetooth).

Сервіс `a9e10001-7c1e-4b6f-9d2a-41676e744c69`, значення — JSON до 500 байтів:

| Характеристика | Доступ | Значення |
|---|---|---|
| `a9e10002-…` status | читання | `{"name", "state", "portal", "ssid", "ip", "rssi", "saved": [...]}`, оновлюється щосекунди |
| `a9e10003-…` scan | читання | `{"seq", "list": [...]}` — результат останнього пошуку мереж |
| `a9e10004-…` cmd | запис | `{"cmd":"scan"}`, `{"cmd":"add","ssid","pass"}`, `{"cmd":"forget","ssid"}`, `{"cmd":"forget"}` |

Після `scan` клієнт перечитує характеристику scan, доки не зміниться `seq` (пошук триває кілька секунд). Після `add` і `forget` лампа перезавантажується. Збережених паролів лампа по Bluetooth не віддає. Цей сервіс працює без спарювання й шифрування.

## Що де в коді

| Файл у `firmware/` | Що там |
|---|---|
| `src/app.h` | спільні оголошення всіх модулів |
| `src/main.cpp` | `setup()` і `loop()` |
| `src/settings.cpp` | налаштування у флеші |
| `src/agents.cpp` | список агентів і загальний стан |
| `src/light.cpp` | діоди й анімації |
| `src/touch.cpp`, `src/gesture.h` | дії сенсора і розпізнавання жестів |
| `src/timer.cpp`, `src/focus.h` | таймер фокусу |
| `src/play.cpp`, `src/games.h` | ігри |
| `src/net.cpp` | WiFi: збережені мережі, точка доступу з порталом |
| `src/api.cpp` | веб-сервер, REST, налаштування |
| `src/mcp.cpp` | MCP-сервер |
| `src/hook.cpp` | прийом хуків агентів у їхньому форматі |
| `src/ble.cpp` | налаштування WiFi по Bluetooth |
| `src/ota.cpp` | оновлення по WiFi: перевірка підпису або пароля |
| `src/allow.cpp`, `src/allow_rules.h` | «Дозволити»: спарювання, запити, підпис відповіді; правила, що можна дозволяти |
| `src/page.html` | сторінка лампи; перед збіркою разом із файлами з `hooks/` пакується в `assets.h` скриптом `tools/embed_assets.py` |
| `test_fw/main.cpp` | тестова прошивка |

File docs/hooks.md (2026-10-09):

# Підключення агентів

Лампа сама містить усе потрібне: готові хуки для кожного агента і встановлювач. Репозиторій для підключення не потрібен.

## Одна команда

На сторінці лампи: «Підключення агентів» → вибрати агента → скопіювати команду. Вона виглядає так:

```sh
curl -4 -fsS http://agentlight.local/install.sh | sh -s -- claude
```

Замість `claude` — `opencode`, `codex`, `gemini`, `antigravity`, `copilot`, `qwen` або `cursor`. Команду можна виконати самому в терміналі або дати агентові й попросити виконати. Після цього агента треба перезапустити.

Що робить встановлювач:

- завантажує з лампи хуки для вибраного агента;
- дописує їх до його налаштувань, не чіпаючи чужих хуків; повторний запуск замінює свої старі записи, а не дублює;
- попередню версію файлу лишає поруч як `*.bak-agentlight-<час>`.

Що потрібно на комп'ютері: `curl` і, якщо в агента вже є налаштування, `python3` або `node` для їх об'єднання. Без них встановлювач нічого не змінює і показує, який файл додати вручну. Windows без WSL не підтримується.

| Агент | Куди ставиться |
|---|---|
| Claude Code | `~/.claude/settings.json` |
| OpenCode | `~/.config/opencode/plugins/agentlight.js` |
| Codex CLI | `~/.codex/hooks.json` |
| Gemini CLI | `~/.gemini/settings.json` |
| Antigravity | `~/.gemini/config/hooks.json` |
| Copilot CLI | `~/.copilot/hooks/agentlight.json` |
| Qwen Code | `~/.qwen/settings.json` |
| Cursor | `~/.cursor/hooks.json` |

## Дозволити з лампи (експериментально)

Те саме встановлення зі словом `allow` — лише для `claude` й `opencode`:

```sh
curl -4 -fsS http://agentlight.local/install.sh | sh -s -- claude allow
```

Команда спаровує комп'ютер із лампою (попросить торкнутись її), кладе секрет у `~/.agentlight/allow.conf` і додає хук, який питає лампу про дозвіл. Що це таке і які має запобіжники — у [firmware.md](firmware.md), розділ «Дозволити».

## Як це влаштовано

Хук — це один виклик `curl`: він бере перші 4 КБ події агента і шле їх лампі як є.

```sh
d=$(head -c 4000); printf %s "$d" | curl -4 -s -m 2 -o /dev/null -X POST -H 'Content-Type: application/json' \
  --data-binary @- http://agentlight.local/hook/claude/busy >/dev/null 2>&1 &
```

Лампа сама дістає з події сесію, теку проєкту, запит і поточну дію (`firmware/src/hook.cpp`). Тому на комп'ютері немає ні скриптів, ні `jq`, а запит іде у фоні з обмеженням 2 секунди й агента не гальмує.

Адреса запиту: `/hook/<агент>/<стан>`. Стан — `busy`, `waiting`, `done`, `error`, `idle` або псевдостан, який лампа уточнює за вмістом події:

- `stop` — кінець ходу з причиною (Cursor, Antigravity): успіх, помилка, переривання або «фонові задачі ще йдуть»;
- `notification` — сповіщення: «чекає» лише для запиту дозволу чи питання, решта ігнорується.

OpenCode підключається інакше — плагіном, який працює всередині нього і шле стан на `/api/status`.

Хуки звертаються до лампи за іменем `agentlight.local`. Якщо в мережі воно не працює (частина Linux-систем без mDNS), заміни його у встановленому файлі на IP-адресу лампи.

## Які події який стан дають

| Агент | працює | чекає | готово | помилка | спокій |
|---|---|---|---|---|---|
| Claude Code | UserPromptSubmit, PostToolUse, PostToolUseFailure, PermissionDenied, ElicitationResult, PreCompact | PermissionRequest, PreToolUse (AskUserQuestion), Elicitation, Notification | Stop | StopFailure | SessionEnd |
| OpenCode | chat.message, tool.execute.before, session.status, permission.replied | permission.asked, question.asked | session.status idle | session.error | session.deleted, переривання |
| Codex CLI | UserPromptSubmit, PostToolUse | PermissionRequest | Stop | — | Interrupt, SessionEnd |
| Gemini CLI | BeforeAgent, BeforeTool | Notification | AfterAgent | — | SessionEnd |
| Antigravity | PreInvocation | — | Stop | Stop з помилкою | — |
| Copilot CLI | userPromptSubmitted, postToolUse, postToolUseFailure | notification | agentStop | errorOccurred | sessionEnd |
| Qwen Code | UserPromptSubmit, PostToolUse, PostToolUseFailure, PermissionDenied | PermissionRequest, Notification | Stop | StopFailure | SessionEnd |
| Cursor | beforeSubmitPrompt, postToolUse, postToolUseFailure | — | stop | stop з помилкою | sessionEnd, переривання |

## Що перевірено

| Агент | Стан перевірки |
|---|---|
| Claude Code | усі п'ять станів на справжній програмі: «працює» із запитом, дія інструмента, «чекає» з назвою дії, «готово», «помилка», «спокій» після закриття |
| OpenCode | «працює» з назвою інструмента і «готово» на справжньому OpenCode; запит дозволу, питання, помилка й переривання — ні |
| Antigravity | «працює» і «готово» на справжньому Antigravity IDE 2.5.5, вручну; помилка й фонові задачі — лише пробними подіями |
| Codex CLI | «працює» (із запитом і назвою проєкту) і закриття сесії на справжньому Codex без входу в акаунт; «готово» й «чекає» — лише пробними подіями |
| Qwen Code | «працює» на справжньому Qwen Code без входу в акаунт; решта — ні |
| Copilot CLI | на справжньому не перевірено: без входу в GitHub він не запускає сесію; лише пробні події |
| Cursor | лише пробними подіями: програми немає |
| Gemini CLI | не перевірено: не запускається без платного ключа |

Claude Code, Codex, Qwen і OpenCode перевіряються автоматично: щотижня на свіжих версіях ([testing.md](testing.md)) і в наскрізній перевірці лампи ([e2e-report.md](e2e-report.md)).

Встановлювач для всіх восьми агентів перевірений у порожній домашній теці: файли лягають на місця, чужі хуки зберігаються, повторний запуск нічого не дублює.

Відомі особливості:

- **OpenCode з плагіном oh-my-openagent сам запускає хуки Claude Code**, але без події завершення. Лампа такі виклики пропускає (сесії з ідентифікатором `ses_…`); їх веде плагін OpenCode.
- **Antigravity не має стану «чекає».** Єдиний спосіб його зловити — хук перед інструментом, а він мусить повертати рішення про дозвіл, і з документації незрозуміло, яке безпечне.
- **Codex не запускає нові хуки, доки їх не схвалено.** Після встановлення він при першому запуску попросить переглянути хуки й довірити їм — без цього лампа мовчатиме.
- **Qwen Code при помилці з'єднання з сервером не шле ні помилки, ні завершення сесії** — лампа лишається в «працює», доки не спливе час цього стану.
- **Cursor** за документацією сам імпортує хуки з `~/.claude/settings.json`; тоді сесії Cursor з'являться на лампі як сесії Claude Code, і окремі хуки Cursor дадуть дублі.

## Перевірка без агента

```sh
echo '{"session_id":"test1234","cwd":"/tmp/demo","hook_event_name":"UserPromptSubmit","prompt":"привіт"}' \
  | curl -4 -s -X POST -H 'Content-Type: application/json' --data-binary @- http://agentlight.local/hook/claude/busy
```

Лампа має показати «працює», а на її сторінці з'явиться картка `demo`.

## Звідки файли

Джерело — тека `hooks/` репозиторію: по одному файлу на агента і `install.sh`. Під час збірки прошивки `firmware/tools/embed_assets.py` пакує їх у прошивку, і лампа роздає їх за адресами `/setup/<файл>` та `/install.sh`.

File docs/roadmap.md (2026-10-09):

# План

Що вже є — у [firmware.md](firmware.md). Усе, що планувалось до версії 0.12, зроблено:

| Версія | Що додала |
|---|---|
| 0.7 | оновлення однією кнопкою: підписані збірки з GitHub |
| 0.8 | вибір режиму довгим утриманням; режим «Фокус»; таймер сну; дії «сигнал агентові», «запит на адресу», «спалах» |
| 0.9 | режим «Ігри»: шість ігор, рекорди |
| 0.10 | режим «Музика», медіа-клавіші та F13–F16 як дії сенсора |
| 0.11 | «Дозволити» для Claude Code й OpenCode — **експериментально** |
| 0.12 | вибір пристрою, якому пульт шле клавіші |

## Що можна зробити далі

Нічого з цього не розпочато; порядок довільний.

- **Обмежувач струму діодів.** Прошивка рахує струм кадру й притьмарює, якщо він вищий за межу. Потрібен, якщо білий на повній яскравості помітно гріє корпус.
- **Дія сенсора «наступний пристрій»** для пульта — зараз активний пристрій вибирається лише на сторінці.
- **«Дозволити» для Codex CLI і Qwen Code** — див. нижче.
- **Сторінка лампи англійською** — зараз лише українська.
- **Автоматичний відкат** прошивки, яка після оновлення не вийшла в WiFi.
- **Захист сторінки й API** паролем: зараз керувати лампою може кожен у тій самій мережі.

Обмеження, яке треба тримати в голові: прошивка займає близько 90% слота, лишилось приблизно 135 КБ.

## «Дозволити»: інші агенти

Зроблено для Claude Code й OpenCode; як воно працює і які має запобіжники — у [firmware.md](firmware.md). Далі — що відомо про решту.

Працюватиме лише там, де агент дає хукові чи плагіну вирішувати за користувача. За документацією й вихідним кодом станом на 2026-10-09 (нічого з цього ще не перевірено на справжніх програмах):

| Агент | Може дозволити | Знає, що питання справді з'явиться | Питання в терміналі під час очікування | Висновок |
|---|---|---|---|---|
| OpenCode | так, плагін відповідає на подію `permission.asked` | так | видно; перемагає перша відповідь | найкращий випадок |
| Claude Code | так, хук `PermissionRequest` | так | у документації не сказано — треба перевірити | підходить |
| Codex CLI | так, хук `PermissionRequest` | так | ймовірно, затримується | підходить |
| Qwen Code | так, хук `PermissionRequest` | так | не сказано | підходить |
| Antigravity | так, `PreToolUse` з рішенням | ні | ймовірно, затримується | лише для вузького переліку інструментів: інакше лампа питатиме й про те, що дозволено й так |
| Copilot CLI | так, крім обходу пісочниці | ні: хук спрацьовує до перевірки правил | затримується | те саме |
| Cursor | не підтверджено | ні | — | поки ні |
| Gemini CLI | ні, хук може лише заборонити | ні | — | неможливо |

Якщо хук не відповів чи не встиг, усі придатні агенти показують звичайне питання — тобто відмова лампи не ламає роботу.

Наступні кандидати — Codex CLI і Qwen Code: їхній хук має той самий формат відповіді, що й у Claude Code.

Відома ціна: у Claude Code хук спрацьовує до показу питання, тож з увімкненою функцією кожне питання в терміналі з'являється із затримкою на час очікування дотику.

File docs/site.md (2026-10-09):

# Сайт

Тека `web/` — статичний сайт без серверної частини:

| Сторінка | Що робить |
|---|---|
| `web/index.html` | вхід: посилання на налаштування і на превью корпусу |
| `web/setup.html` | налаштування WiFi лампи по Bluetooth |
| `case/preview/index.html` | 3D-превью корпусу, схема, файли до друку |

## Локально

```sh
python3 web/serve.py           # http://localhost:8791/web/
python3 web/serve.py --lan     # ще й для інших пристроїв у мережі
python3 web/serve.py --port 9000
```

Сервер віддає корінь репозиторію, бо сайт посилається на `case/preview/` і `case/stl/`. Потрібен лише Python 3, без залежностей.

## Налаштування по Bluetooth

1. Відкрий `http://localhost:8791/web/setup.html` у Chrome або Edge.
2. Натисни «Знайти лампу» і вибери `AgentLight-XXXX`.
3. Вибери мережу, введи пароль, натисни «Додати і підключитись».
4. Лампа перезавантажиться; сторінка підключиться до неї знову й покаже адресу сторінки лампи.

Лампа пам'ятає до п'яти мереж і сама підключається до тієї, яку бачить поруч, — можна додати домашню й офісну.

Обмеження:

- **Браузер.** Chrome або Edge на Mac, Windows, Android, Linux, ChromeOS. Safari, Firefox і всі браузери на iPhone Bluetooth зі сторінок не вміють. З iPhone налаштовуй через точку доступу лампи: підключись до `AgentLight-XXXX`, сторінка відкриється сама.
- **Адреса.** Chrome дає Bluetooth лише сторінкам з `localhost` або з HTTPS. З `--lan` інші пристрої відкриють сайт по `http://<ip>:8791`, але Bluetooth там не працюватиме.
- **Відстань.** Лампа має бути поруч, до ≈ 10 м.

## Де сайт живе в інтернеті

**GitHub Pages:** https://onelenyk.github.io/agentlight/ — публікується сам при кожному релізі прошивки (`.github/workflows/release.yml`). Там сторінка налаштування по Bluetooth, 3D-превью корпусу, файли до друку й остання прошивка з файлом `firmware/latest.json`, з якого сторінка лампи дізнається про оновлення.

**Окремий сайт зі сторінкою налаштування:** https://agentlight.onelenyk.dev/ — збирається з `Dockerfile` у корені репозиторію (nginx із самим `web/setup.html`).

Обидва працюють по HTTPS, тож Bluetooth у Chrome там доступний звідусіль. Пароль WiFi через сайт не проходить: він іде з браузера прямо на лампу по Bluetooth.

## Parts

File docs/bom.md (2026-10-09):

# Компоненти

## Електроніка

| Деталь | Кількість | Примітка |
|---|---|---|
| ESP32-C3 Super Mini | 1 | плата 22,5 × 18 мм з USB-C; від USB і живиться, і прошивається |
| WS2812B на круглій платці Ø9,5 мм | 3 | адресний RGB-діод 5050, контакти ззаду: 5V, GND, DIN, DOUT |
| Модуль TTP223, сенсорна кнопка | 1 | червоний модуль ≈ 15 × 11 мм, контакти VCC, I/O, GND; живлення 2,0–5,5 В |
| Резистор 330 Ом | 1 | у розрив дроту даних до першого діода; 0,125–0,25 Вт |
| Дріт 28 AWG у силіконовій ізоляції | ≈ 0,7 м | бажано п'ять кольорів: червоний, чорний, зелений, жовтий, синій |
| Термозбіжна трубка Ø2 мм | ≈ 3 см | на резистор |
| Кабель USB-C | 1 | штекер має пролазити в отвір 14 × 8 мм |

Лампа працює і з одним діодом, і без сенсора: прошивка сама цього не перевіряє, просто світить у порожній вихід і не чує дотиків.

## Живлення

Розрахунок за паспортом WS2812B (до 20 мА на кожен із трьох кольорів кристала), не вимір; справжні діоди зазвичай беруть на 10–20% менше. Три діоди, повна яскравість:

| Що світить | Струм | Потужність |
|---|---|---|
| білий — максимум | 180 мА | 0,9 Вт |
| теплий білий (режим лампи) | 124 мА | 0,6 Вт |
| працює (оранжевий) | 81 мА | 0,4 Вт |
| готово (зелений) | 67 мА | 0,3 Вт |
| чекає, помилка (червоний) | 60 мА | 0,3 Вт |

Струм пропорційний яскравості, анімації беруть менше за рівне світло.

Діоди живляться від контакту 5V, тобто прямо від USB, повз стабілізатор плати. Сама плата з WiFi та Bluetooth бере в середньому близько 100 мА з короткими піками до 300–350 мА. Разом у найгіршу мить — близько 500 мА, що дає звичайний порт USB 2.0; у середньому 150–300 мА.

На що зважати: білий на повній яскравості — це понад ват тепла в закритому корпусі з PLA, який м'якне близько 55–60 °C; чи гріється ковпак, варто перевірити рукою. Більше десяти діодів чи довгу стрічку треба живити окремо.

## Друк

| Філамент | Деталі | Об'єм суцільного тіла |
|---|---|---|
| чорний | основа | 7,0 см³ |
| білий | диск із кишенями, розсіювач, рамка | 5,0 см³ |
| прозорий | ковпак | 5,1 см³ |

Разом до ≈ 21 г PLA, якби деталі були суцільні; з заповненням слайсера вийде менше. Потрібен принтер із соплом 0,4 мм і столом від 100 мм; друкувалось на Bambu A1 mini без AMS — кожен колір окремою плитою.

Кольори можна міняти: на сторінці превью (`case/preview/`) є вибір філаменту для кожної деталі з підказкою, як він вплине на світло.

## Інше

- Крапля клею: закріпити платки діодів у кишенях і сенсор у гнізді.
- Паяльник, припій, бокорізи.
- Штангенциркуль: перед друком варто звірити товщину плати, платки діода і розміри сенсора з тими, що в `case/build.py`.

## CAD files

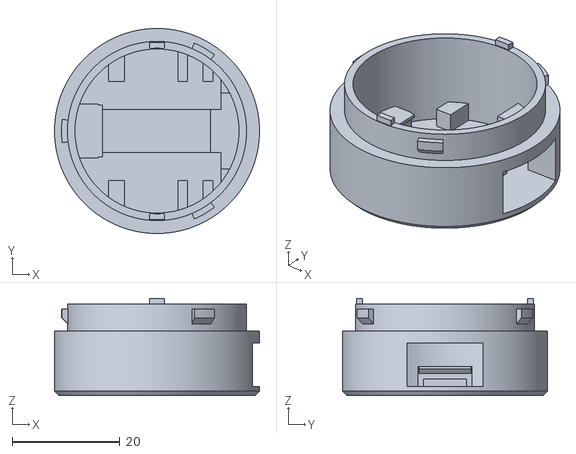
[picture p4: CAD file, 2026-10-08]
case/stl/base.stl
38.0 x 38.0 x 18.0

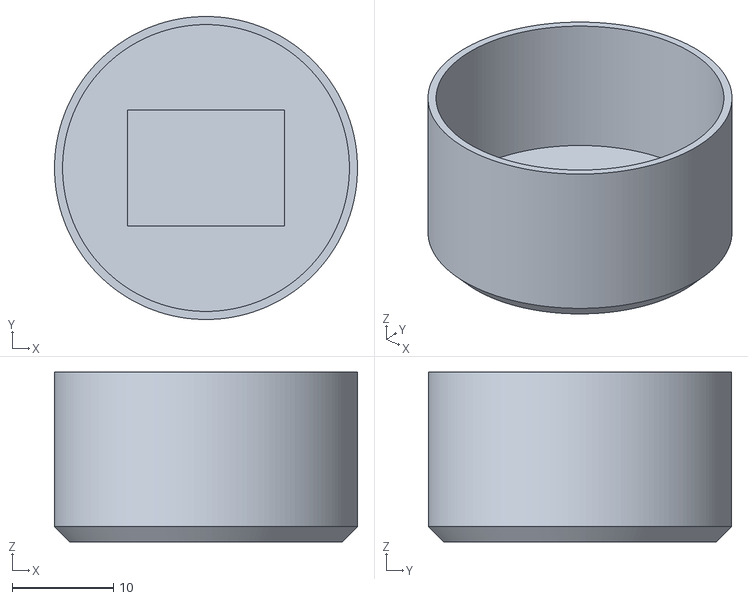
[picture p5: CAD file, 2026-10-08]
case/stl/diffuser.stl
30.0 x 30.0 x 16.8

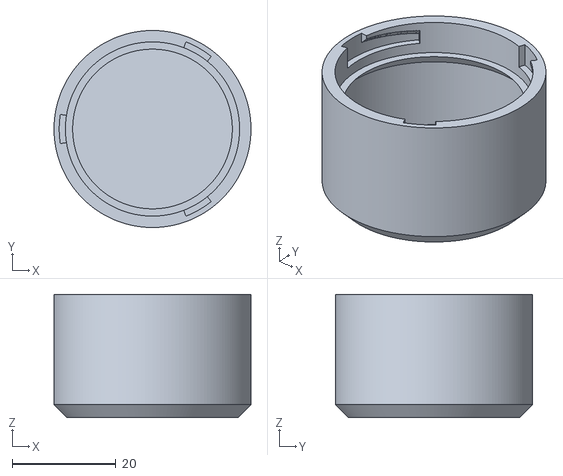
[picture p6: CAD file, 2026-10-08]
case/stl/dome.stl
38.0 x 38.0 x 23.8

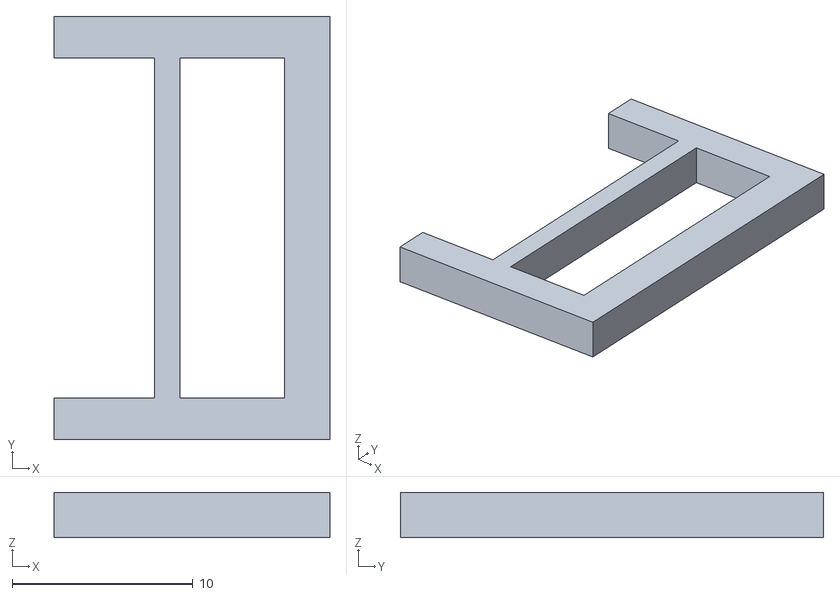
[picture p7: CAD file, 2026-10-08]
case/stl/clamp.stl
15.2 x 23.4 x 2.50

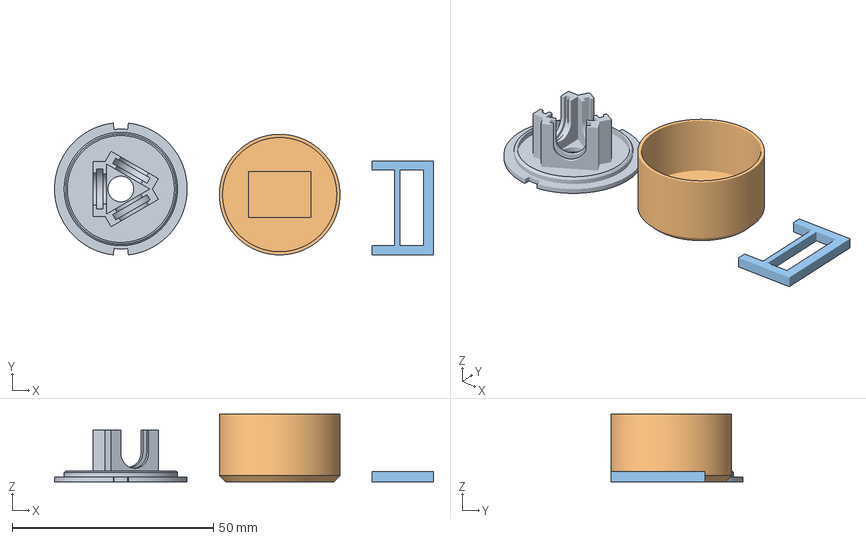
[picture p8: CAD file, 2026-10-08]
case/stl/plate_white.3mf
94.2 x 32.8 x 16.8 mm
carrier
diffuser
clamp

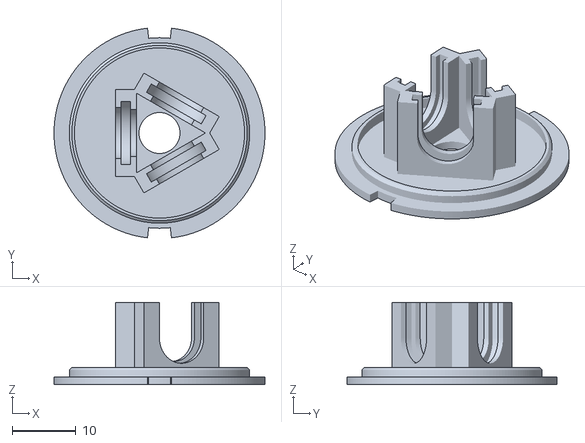
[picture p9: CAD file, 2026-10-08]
case/stl/carrier.stl
33.0 x 32.8 x 12.9

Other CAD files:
case/stl/plate_black.3mf
case/stl/plate_clear.3mf

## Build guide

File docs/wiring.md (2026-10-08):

# Підключення і пайка

Схема підключення

Векторна версія: [images/wiring.svg](images/wiring.svg). Дуга на схемі означає, що дріт перестрибує інший без з'єднання; з'єднання позначені крапкою.

## Що куди

Лівий ряд плати, якщо дивитись зверху з USB угору: 5V, GND, 3V3, GPIO4, GPIO3, GPIO2, GPIO1, GPIO0.

| Дріт | Звідки → куди | Довжина |
|---|---|---|
| червоний | **5V** плати → 5V платки 1, далі на 5V платок 2 і 3 | ≈ 65 + 2 × 30 мм |
| чорний | **GND** плати → GND платки 1, далі на GND платок 2 і 3 | ≈ 65 + 2 × 30 мм |
| зелений | **GPIO3** → резистор 330 Ом → DIN платки 1 | ≈ 65 мм |
| зелений | DOUT платки 1 → DIN платки 2, DOUT платки 2 → DIN платки 3 | 2 × 30 мм |
| жовтий | **3V3** плати → VCC сенсора | ≈ 80 мм |
| чорний | **GND** → GND сенсора | ≈ 80 мм |
| синій | I/O сенсора → **GPIO1** | ≈ 80 мм |

Довжини прикинуті з моделі, а не з готового виробу — лиши запас 1–2 см.

Зауваги:

- **GND на платі один.** Землю сенсора можна взяти з контакту GND будь-якої платки діода (так на схемі) або впаяти другий дріт у той самий отвір плати.
- **Сенсор живи від 3V3, не від 5V:** тоді його вихід має безпечний для плати рівень.
- **Не чіпай GPIO2, GPIO8, GPIO9** — від них залежить завантаження плати.
- **Дані діодів — GPIO3.** Інший пін задається прапорцем `LED_PIN` у `firmware/platformio.ini`.
- **Стрілка на платці діода** показує напрям від DIN до DOUT.

## Порядок пайки

Кінці дротів до плати ESP паяються останніми: платки діодів і сенсор не пролазять крізь колодязь у диску (Ø6,4 мм), тож дроти треба спершу протягнути.

1. **Наріж дроти** за таблицею.
2. **Спаяй ланцюжок діодів.** До платки 1 — три довгі дроти (5V, GND, DIN), далі перемички до платки 2 і від неї до платки 3.
3. **Припаяй три дроти до сенсора** (VCC, GND, I/O).
4. **Перевір без корпусу.** Залий тестову прошивку (`cd firmware && pio run -e touchtest -t upload`), тимчасово прихопи дроти до плати: діоди мають світитись, поки палець на сенсорі.
5. **Засунь платки в кишені диска** згори, діодами назовні, дроти — в колодязь по центру, вниз. Закріпи краплею клею.
6. **Вклей сенсор у гніздо розсіювача** гладким боком до стелі, пропусти його дроти в той самий колодязь і надягни розсіювач на диск.
7. **Припаяй дроти до плати ESP** згори, з боку USB-роз'єму. Резистор — у розрив дроту GPIO3, у термозбіжку біля плати. Знизу хвостики обріж до 1,5 мм: під платою лише стільки місця.
8. **Залий основну прошивку** і збери корпус.

## Складання корпусу

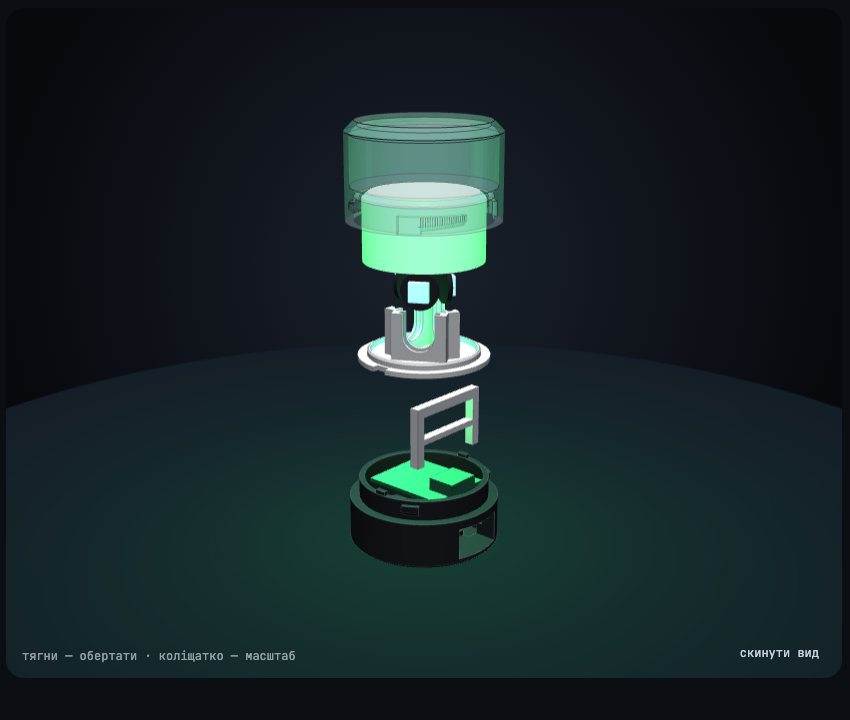
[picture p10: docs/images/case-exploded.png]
Корпус у розібраному вигляді


1. Заведи плату заднім краєм під гачок і поклади в основу, USB — у тунель.
2. Встав рамку ніжками в пази: нижня перекладина ляже на роз'єм.
3. Поклади диск із діодами й розсіювачем на шийку, вирізами на два шипи.
4. Надягни ковпак і поверни за годинниковою стрілкою приблизно на 25°, доки не затягнеться.

Ковпак притискає розсіювач до диска, а диск до шийки; диск не дає піднятись рамці, яка тримає плату за USB-роз'єм. Тому плата сидить щільно лише із закрученим ковпаком.

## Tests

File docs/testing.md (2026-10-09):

# Тести

Усе, що з'єднує агентів із лампою, перевіряється без самої лампи — локально й у GitHub Actions.

```sh
python3 -m unittest discover -s tests -v    # ~7 секунд; потрібні python3, компілятор C++, curl, openssl, node
python3 tests/canary.py                     # справжні CLI агентів; потрібні node і npm, ~1,5 хвилини
```

## Що перевіряється на кожен коміт

Файл `.github/workflows/ci.yml`, три завдання.

**Хуки, розбір подій, встановлювач** (`tests/test_agentlight.py`):

| Група | Що ловить |
|---|---|
| розбір подій | лампа неправильно зрозуміла подію агента: не той стан, сесія, проєкт, запит чи дія. 30 зразків подій у `tests/hook_cases.json` для семи агентів, зокрема обрізані посередині, з українським текстом, з порожнім тілом |
| файли хуків | файл `hooks/<агент>.json` має форму, яку агент не прийме, або шле не на ту адресу лампи. Тут зафіксована форма, на якій уже спіткнулись: Antigravity відкидав увесь файл через зайвий рівень вкладеності |
| встановлювач | `install.sh` затер чужі хуки чи налаштування, продублював свої при повторному запуску, зіпсував файл без `python3` і `node`, перезаписав пошкоджений файл |
| наскрізний шлях | встановлений хук, запущений як його запускає агент, не доходить до лампи, друкує зайве або затримує агента, коли лампа вимкнена |
| «Дозволити» | хук дозволив те, чого не мав: лампа відмовилась, час вийшов, підпис чужий, комп'ютер не спарований; секрет читається іншими користувачами; небезпечна команда не розпізнана; у звичайну збірку потрапив шлях «дотик запитом» |
| ігри | раунд рахується не так: фальстарт, влучання й промах, помилка в «10 секундах», порівняння ритму, рекорд, що не оновлюється чи оновлюється гіршим результатом |
| жести й таймер фокусу | дотик розпізнано не так (подвійний замість двох окремих, утримання замість вибору режиму), таймер рахує під час паузи, не переходить між роботою й перервою, ламається на переповненні лічильника часу |
| реліз прошивки | підпис не сходиться з файлом, `latest.json` описує не той файл, у репозиторій потрапив закритий ключ, сторінка лампи й процес публікації розійшлись в адресі оновлень |

Розбір подій — це той самий файл `firmware/src/hook_parse.h`, що йде в прошивку: тести збирають його на комп'ютері (`tests/hookparse.cpp`). Замість лампи працює `tests/mock_lamp.py` з тими самими адресами; файли він, як і лампа, віддає стиснутими.

**Збірка прошивки.** Обидві прошивки збираються; збірка падає і тоді, коли прошивка перестає влазити в слот 1,25 МБ.

**Корпус.** Модель перебудовується й проходить `case/verify.py`.

## Що перевіряється раз на тиждень

Файл `.github/workflows/canary.yml`, скрипт `tests/canary.py`. Він ставить найсвіжіші версії справжніх CLI, підключає їх нашим встановлювачем до імітації лампи й запускає без входу в акаунт.

| Агент | Як запускається | Що перевіряє |
|---|---|---|
| Claude Code | повні ходи проти імітації API моделі (`tests/mock_model.py`): відповідь, виклик інструмента, помилка API | що Claude Code читає наш файл хуків і шле лампі «працює» із запитом і проєктом, дію інструмента, «готово», «помилку», «спокій» після закриття сесії |
| Codex CLI | один запит; запит до OpenAI падає з 401 | що Codex приймає файл хуків і шле «працює» із запитом і проєктом, а після завершення — «спокій» |
| Qwen Code | один запит до недосяжного сервера | що Qwen приймає файл хуків і шле «працює» із запитом і проєктом |

Червоний запуск означає: агент змінив формат файлу хуків чи полів події, і з його новою версією лампа, найімовірніше, показує не те. Перевірено навмисною поломкою: якщо зіпсувати форму запису `Stop` у `hooks/claude.json`, канарка падає, бо «готово» не приходить.

Особливості:

- **Claude Code запускається через потоковий інтерфейс**, а не `claude -p "..."`: у звичайному неінтерактивному запуску фонові хуки кінця ходу обриває вихід із програми.
- **Імітація моделі відповідає з паузою пів секунди.** Хуки фонові, тож «запит надіслано» і «хід завершено», надіслані майже одночасно, можуть дійти до лампи в зворотному порядку — тоді лампа лишилась би в «працює». Справжня модель думає довше, ніж іде запит до лампи, тому в житті цього не видно, але гарантії порядку немає.
- **Помилка API в тесті — 400.** Помилки 401, 429 і 5xx Claude Code повторює хвилинами, перш ніж здатися.

## Наскрізна перевірка справжньої лампи

`tests/e2e_lamp.py` проходить по живій лампі в мережі все, що не потребує пальця на сенсорі й очей: агентів, хуки, справжні програми агентів, MCP, режими й таймери, ігри, WiFi і Bluetooth, оновлення прошивки, «Дозволити», сайт. Близько 60 перевірок, 12–15 хвилин. Вона міняє налаштування лампи, кілька разів її перезавантажує та оновлює, а наприкінці повертає все як було.

```sh
python3 tests/e2e_lamp.py --lamp 192.168.1.50                 # усе
python3 tests/e2e_lamp.py --lamp 192.168.1.50 --only cli,mcp  # вибрані розділи
```

У CI вона не запускається: потрібна лампа. Розділ «Дозволити» повний лише на збірці з прапорцем `ALLOW_TEST_TOUCH` — у звичайній «торкнутись» лампи запитом не можна.

## Чого не бачить жодна перевірка

- **Палець і очі.** Жести на живому сенсорі, вигляд анімацій, ігри на швидкість — лише руками. Розпізнавання жестів, таймер та ігри покриті тестами логіки, але не на самому сенсорі.
- **Агентів, яких не запустити без акаунта чи вікна:** Antigravity, Copilot CLI, Cursor, Gemini CLI. Для них зафіксований лише формат, який ми вже бачили робочим або взяли з документації; зміну формату з боку агента тести не помітять.
- **Стани після запиту до моделі** в Codex і Qwen: для них немає імітації моделі.
- **Запит дозволу в інтерактивному вікні** агента: у перевірках агенти працюють без вікна.

Що покрито лише наскрізною перевіркою, тобто не на кожен коміт, а коли її запускають із лампою: режими, анімації, таймери на самій платі, API налаштувань, WiFi, Bluetooth, оновлення прошивки.

## Як додати зразок події

Коли агент прислав подію, яку лампа зрозуміла не так: додай її в `tests/hook_cases.json` з очікуваним результатом, переконайся, що тест падає, і виправ `firmware/src/hook_parse.h`.

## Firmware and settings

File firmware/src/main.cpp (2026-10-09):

// AgentLight: ESP32-C3 Super Mini + WS2812. Показує кольором статус AI-агента.
// Перший старт: точка доступу AgentLight-XXXX з порталом для налаштування WiFi (або по Bluetooth, web/setup.html).
// Далі: http://agentlight.local/ — сторінка, /api/status — REST, /mcp — MCP-сервер.
// Модулі описані в app.h, запити — у docs/firmware.md.
#include <WiFi.h>
#include "app.h"

void setup() {
  Serial.begin(115200);
  loadSettings();
  lightBegin();
  touchBegin();
  netBegin();
  bleBegin();
  playBegin();
  apiBegin();
}

void loop() {
  pollNet();
  server.handleClient();
  pollTouch();
  pollBle();
  pollOta();
  pollFocus();
  pollPlay();
  pollAllow();
  render();

  static uint32_t lastLog = 0;
  if (millis() - lastLog > 5000) {
    lastLog = millis();
    Serial.printf("[%lus] %s, стан: %s, ip: %s\n", lastLog / 1000, portal ? "портал" : "WiFi",
                  STATE_NAMES[aggregate()], (portal ? WiFi.softAPIP() : WiFi.localIP()).toString().c_str());
  }
}

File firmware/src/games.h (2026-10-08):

// Ігри на одному сенсорі й кількох діодах. Чистий C++ без Arduino — у прошивці (play.cpp) і в тестах на комп'ютері.
// Грі кажуть, коли палець торкнувся й коли відпустив, і часто викликають tick(); вона каже, чим світити кожному діоду.
//
//   REACTION  червоне — чекай; зелене — торкнись якнайшвидше. Результат: мілісекунди, менше — краще
//   STOP      вогник біжить по колу; зупини його на позначеному діоді. Результат: влучань поспіль, більше — краще
//   TEN       торкнись, і ще раз — коли, на твою думку, минуло 10 секунд. Результат: помилка в мс, менше — краще
//   RHYTHM    лампа блимає короткі й довгі спалахи; повтори їх дотиками. Результат: пройдено раундів
//   MARATHON  скільки дотиків за 10 секунд
//   DICE      вирішувач: так чи ні, число, колір. Рекорду немає
#pragma once
#include <cstdint>

struct Games {
  enum Game : uint8_t { REACTION, STOP, TEN, RHYTHM, MARATHON, DICE, GAME_COUNT };
  // ECHO — гравець повторює ритм (назву INPUT зайняв макрос Arduino)
  enum Stage : uint8_t { READY, WAIT, GO, RUN, COUNT, PLAY, ECHO, SPIN, RESULT, FAIL, STAGE_COUNT };
  enum Dice : uint8_t { YES_NO, NUMBER, COLOR, DICE_COUNT };
  static const uint8_t  MAX_RHYTHM = 12;
  static const uint32_t RESULT_MS = 3500, FAIL_MS = 1500, GO_TIMEOUT_MS = 3000, TEN_MS = 10000, MARATHON_MS = 10000,
                        SPIN_MS = 1200, LONG_MS = 350, ECHO_TIMEOUT_MS = 5000, FLASH_MS = 400;

  uint8_t  game = REACTION, stage = READY, dice = YES_NO, leds = 3;
  uint32_t last[GAME_COUNT] = {}, best[GAME_COUNT] = {};   // 0 — ще немає
  bool     recordChanged = false;                          // хтось побив рекорд: час зберегти best[]
  uint32_t (*rnd)() = nullptr;                             // джерело випадковості; у тестах — передбачуване

  static bool lowerIsBetter(uint8_t g) { return g == REACTION || g == TEN; }
  bool idle() const { return stage == READY; }

  void select(uint8_t g, uint32_t now) {
    game = g % GAME_COUNT;
    enter(READY, now);
    pressed = false;
    flashUntil = 0;
  }

  void press(uint32_t now) {
    pressed = true;
    pressAt = now;
    bool fresh = stage == READY || stage == RESULT || stage == FAIL;   // можна починати новий раунд
    switch (game) {
      case REACTION:
        if (fresh) { waitMs = 2000 + rnd() % 4001; enter(WAIT, now); }
        else if (stage == WAIT) enter(FAIL, now);                      // фальстарт
        else if (stage == GO) finish(now - stageAt, now);
        break;
      case STOP:
        if (fresh) { level = 0; startPos = rnd() % leds; target = rnd() % leds; enter(RUN, now); }
        else if (stage == RUN) {
          if (runner(now) != target) { finish(level, now); break; }
          level++;
          startPos = (target + 1) % leds;                              // далі біжить із наступного діода, уже швидше
          target = rnd() % leds;
          stageAt = now;
          flashUntil = now + FLASH_MS;
        }
        break;
      case TEN:
        if (fresh) enter(COUNT, now);
        else if (stage == COUNT && now - stageAt >= 1000)              // випадковий другий дотик одразу після першого — не рахуємо
          finish(now - stageAt > TEN_MS ? now - stageAt - TEN_MS : TEN_MS - (now - stageAt), now);
        break;
      case RHYTHM:
        if (fresh) { rounds = 0; length = 3; newPattern(now, 0); }
        break;                                                         // під час ECHO спалах міряється на відпусканні
      case MARATHON:
        if (fresh) { count = 1; enter(COUNT, now); }
        else if (stage == COUNT) count++;
        break;
      case DICE:
        if (stage != SPIN) {
          uint32_t r = rnd();
          value = dice == YES_NO ? r % 2 : dice == NUMBER ? 1 + r % leds : r % 360;
          enter(SPIN, now);
        }
        break;
    }
  }

  void release(uint32_t now) {
    pressed = false;
    if (game != RHYTHM || stage != ECHO) return;
    bool isLong = now - pressAt >= LONG_MS;
    inputAt = now;
    if (isLong != pattern[entered]) { finish(rounds, now); return; }
    if (++entered < length) return;
    rounds++;
    if (length < MAX_RHYTHM) length++;
    flashUntil = now + FLASH_MS;
    newPattern(now, 2 * FLASH_MS);
  }

  void tick(uint32_t now) {
    uint32_t in = now - stageAt;
    switch (stage) {
      case WAIT:   if (in >= waitMs) enter(GO, now); break;
      case GO:     if (in >= GO_TIMEOUT_MS) enter(FAIL, now); break;
      case RUN:    if (in >= 60000) enter(READY, now); break;          // покинули гру
      case COUNT:
        if (game == MARATHON && in >= MARATHON_MS) finish(count, now);
        else if (game == TEN && in >= 3 * TEN_MS) enter(FAIL, now);
        break;
      case PLAY:   if (now >= playEnd) { entered = 0; inputAt = now; enter(ECHO, now); } break;
      case ECHO:  if (!pressed && now - inputAt >= ECHO_TIMEOUT_MS) finish(rounds, now); break;
      case SPIN:   if (in >= SPIN_MS) { last[DICE] = value; enter(RESULT, now); } break;
      case RESULT: if (game != DICE && in >= RESULT_MS) enter(READY, now); break;   // кубик показує відповідь до наступного дотику
      case FAIL:   if (in >= FAIL_MS) enter(READY, now); break;
      default: break;
    }
  }
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

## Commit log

2026-10-08 AgentLight: firmware, case, hooks, setup site and docs
    Status lamp on an ESP32-C3 Super Mini that shows what an AI agent is
    doing: busy, waiting for the user, done.
    - firmware/: PlatformIO project. WiFi captive portal, up to five saved
    networks, device page with debug menu, REST, MCP over HTTP, TTP223
    touch actions, WiFi setup over Bluetooth LE. Separate test firmware
    for checking the soldering.
    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
    [base.stl, carrier.stl, clamp.stl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]
2026-10-08 Додати Dockerfile для хостингу сторінки налаштування
    Сторінка web/setup.html віддається як корінь сайту під nginx:alpine.
    Потрібно для деплою через Coolify (збирає образ із репозиторію).
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2026-10-08 Firmware: split into modules, single LED output, gzipped page
    - main.cpp (700 lines) split into settings, agents, light, touch, net,
    api, mcp and ble modules with one shared header app.h
    - LED data on one pin (LED_PIN=4) instead of mirroring to GPIO3 and 4
    - REST and Bluetooth share one WiFi scan helper
    - device page lives in src/page.html and is gzipped into the firmware
    at build time (12 KB -> 4.5 KB)
    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
2026-10-08 Firmware: OTA updates over WiFi
    - upload firmware.bin from the device page (POST /api/update) or with
    PlatformIO (env ota, espota); both require the update password
    - password is set from the device page and stored in flash; updates stay
    disabled until it is set
    - docs: OTA section, new module layout, LED data on GPIO4 only
2026-10-08 LED data pin is GPIO3: firmware default, wiring diagram and docs
    The assembled lamp has the data wire on GPIO3; with LED_PIN=4 the LEDs
    kept their last colour and ignored updates.
2026-10-08 Firmware: eleven LED animations, selectable per state
    Each state (busy, waiting, done, error) gets its own animation, chosen
    on the device page with a 6-second preview on the lamp. Stored settings
    from the previous layout are kept. Default LED count is now 3.
    [light.cpp]
2026-10-08 Unified five-state model, error state from StopFailure, agent support research
    - hooks: StopFailure -> error, plus PermissionDenied, Elicitation,
    ElicitationResult, PreCompact and more Notification types
    - firmware: idle has its own colour and animation (off by default)
    - docs/agents.md: state model, Claude Code mapping and gaps, and a
    researched (untested) support matrix for OpenCode, Antigravity,
    Gemini CLI, Codex, Cursor, Copilot and others
    [light.cpp]
2026-10-08 Firmware 0.5: agent and lamp modes, per-mode touch gestures, new device page
    - two modes: show agent status, or plain lamp with colour, animation and
    auto-off timer; switch from the page or by touch
    - three gestures (tap, double tap, hold) with actions assigned per mode;
    new actions: switch mode, next animation, next colour
    - rainbow animation
    - device page rebuilt around the modes: every change saves immediately,
    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
2026-10-08 Out of the box: the lamp serves its own hooks and installer, and parses agent events itself
    - POST /hook/<agent>/<state> takes the agent's raw hook payload; the
    firmware extracts session, project, prompt and current action, so a
    hook is a single curl call with no script or jq on the computer
    - GET /install.sh and /setup/<file>: installer and ready hook files for
    eight agents, embedded into the firmware from hooks/
    - installer merges into existing agent settings (python3 or node),
    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
2026-10-08 Tests and CI for the agent integration
    - hook parser moved to portable C++ (firmware/src/hook_parse.h) shared by
    the firmware and host tests
    - tests: 30 event fixtures for seven agents, hook file shapes, installer
    behaviour against a mock lamp, end-to-end hook delivery
    - canary: latest Codex CLI and Qwen Code run against the mock lamp weekly
    - CI: tests, firmware build, case verification
    - fixes found by the tests: a key name appearing as a value hid the real
    key (Antigravity error text was lost); text cut mid-character produced
    invalid UTF-8
2026-10-08 Case: list the packages trimesh needs for 3MF export
    CI caught it: a clean install could not write the print plates.
2026-10-08 Record the remaining manual checks; mock model can call any tool
    Verified: device page and firmware upload form in real Chrome, Bluetooth
    add/forget, choosing among saved networks, MCP tool call from Claude Code,
    hosted setup page.
2026-10-08 Docs: case fit and Bluetooth setup page confirmed on the real device
2026-10-08 Signed firmware updates: one button on the device page, builds published by GitHub Actions
    - the lamp accepts firmware without a password when it carries a valid
    ECDSA P-256 signature made with the project key; the public key is
    embedded in the firmware
    - device page checks latest.json, downloads the build in the browser and
    hands it to the lamp with its signature
    - release workflow: a vX.Y.Z tag builds, signs and publishes the firmware
    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
2026-10-08 Firmware 0.8: focus mode, mode picker by long hold, sleep timer, new touch actions
    - holding the sensor for 2 s cycles through mode colours; release picks
    - focus mode: work/break timer shown as a countdown on the LEDs
    - lamp mode: sleep timer that fades the light out
    - touch actions: signal the agent (visible via MCP), webhook, spark
    - gesture recognition and the focus timer are portable C++ with host tests
    - roadmap: games, music, and an experimental Allow feature
2026-10-08 Firmware 0.9: games mode with six games and saved records
    Reaction, stop-the-light, ten seconds, rhythm, tap marathon and a
    decision dice, all on one touch sensor. Touch reaches the game the
    moment the finger lands. Game logic is portable C++ with host tests.
2026-10-08 Firmware 0.10: Bluetooth remote — music mode, media keys and F13–F16 as touch actions
    The lamp is also a BLE HID keyboard with consumer controls. Pair it once
    in the system's Bluetooth settings; touch actions then send play/pause,
    track and volume keys or F13–F16 to bind commands to. WiFi setup over
    Bluetooth keeps working without pairing.
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2026-10-09 Fixes found by an end-to-end run on the real lamp; add that run as tests/e2e_lamp.py
    - OpenCode plugin never reached the lamp by name: fetch of *.local waits
    5 s for IPv6 on macOS, longer than the plugin's timeout. It now looks
    the lamp up over IPv4 itself, and sends states one at a time, in order
    - Claude Code session-end hook waits for its request instead of leaving
    it to a background process that exit could kill
    - the lamp stays discoverable for Bluetooth WiFi setup while a paired
    computer is connected
    - page buttons for the two keys the macOS keyboard assistant asks for
    - firmware 0.11.1
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2026-10-09 Docs brought up to date; end-to-end report for 0.12.0; checker cleans up after itself
    - README: what the lamp does, current status, real repository address
    - hooks, agents, site, roadmap, testing, components (power budget) updated
    - e2e report: second full run, 67 of 68 passed, one skipped
    - e2e checker: fixed test password removed in its own step, one retry
    for the over-WiFi PlatformIO upload, remote check aware of which
    device is active
    - firmware: a signed build with OTA_FORGET_PASSWORD clears a forgotten
    update password
2026-10-22 Case: USB-C connector held in a snug window in a flat front face
    The board now slides forward into a pocket in the wall so its USB-C
    receptacle sits 0.2 mm behind a flat face, in a window 0.1 mm larger
    than the connector. The plug rests against the face instead of
    wobbling in the old 14 x 8 mm tunnel. A rear latch replaces the clamp
    and the hook: it stops the board sliding back and lifting.
    Only the base and the latch change. Not printed yet; usb_fit_test.stl
    picks the window clearance on a real board.
2026-10-22 Case: room for wires and a snap-on diffuser
    - the wire well in the disc grows from 6.4 to 8 mm, the gap under the
    touch module from 2.3 to 3.8 mm; the lamp is 1.5 mm taller
    - the diffuser snaps onto the disc rim with three beads, so disc, LEDs,
    touch module and diffuser hold together while the dome is screwed on
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
